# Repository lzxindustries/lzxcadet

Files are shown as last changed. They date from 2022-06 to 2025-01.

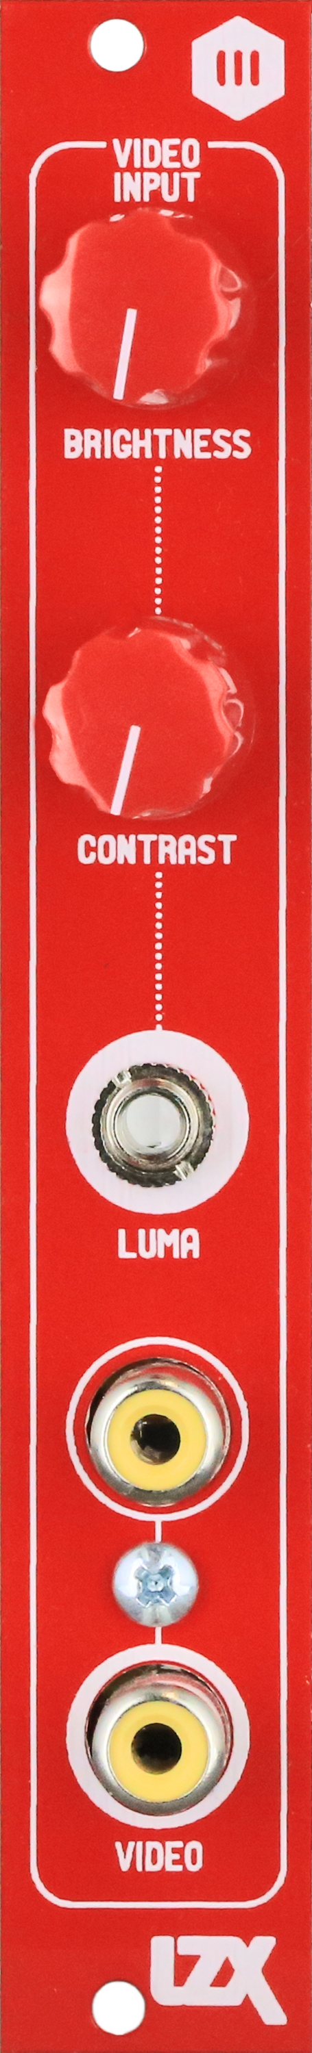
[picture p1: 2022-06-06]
C3/Images/LZX-Industries-Cadet-III-Video-Input-Front-Photo.png

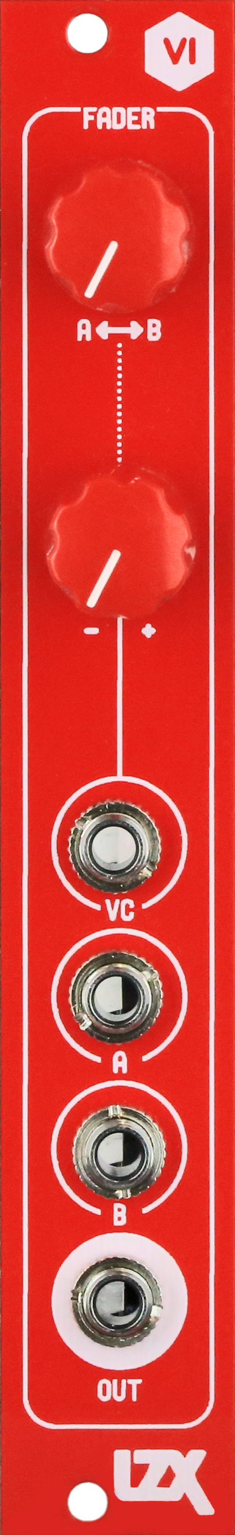
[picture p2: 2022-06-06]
C6/Images/LZX-Industries-Cadet-VI-Fader-Front-Photo.png

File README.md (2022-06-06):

# lzxcadet
LZX Cadet Series EuroRack Video Synthesizer DIY Modules

The designs and release artifacts for these projects are now open source hardware.

* You may fabricate any of the original PCB & Frontpanel Gerbers for personal use without restriction.

* You may not sell these modules, bare PCBs or kits with the original LZX artwork or under the LZX brand name.

* If you sell these modules, open source your derivative work and link back to this repository.

* If anyone is interested in maintaining this repository or revising the designs as a community project, please contact us.

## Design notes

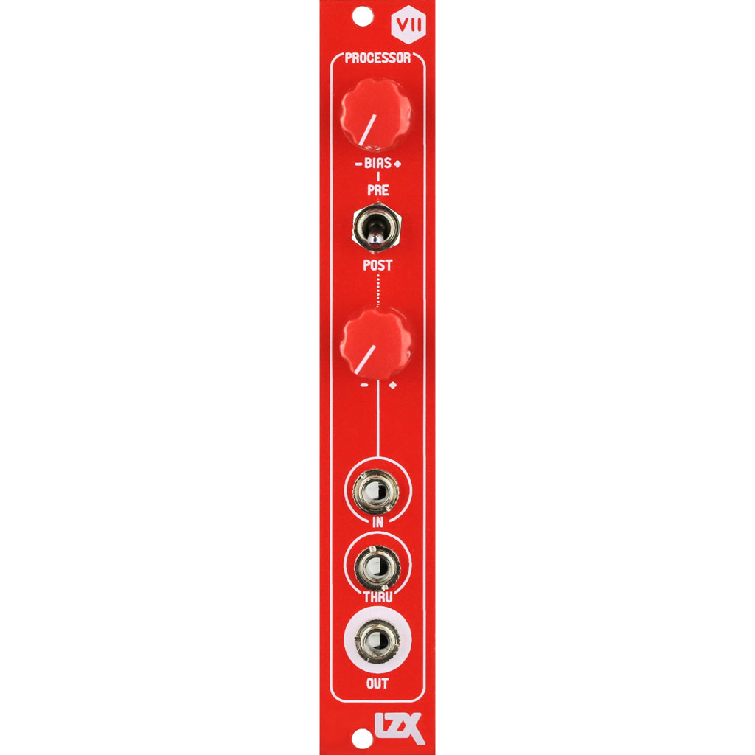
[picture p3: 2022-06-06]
C7/Images/LZX-Industries-Cadet-VII-Processor-Front-Photo_1024X1024.jpg

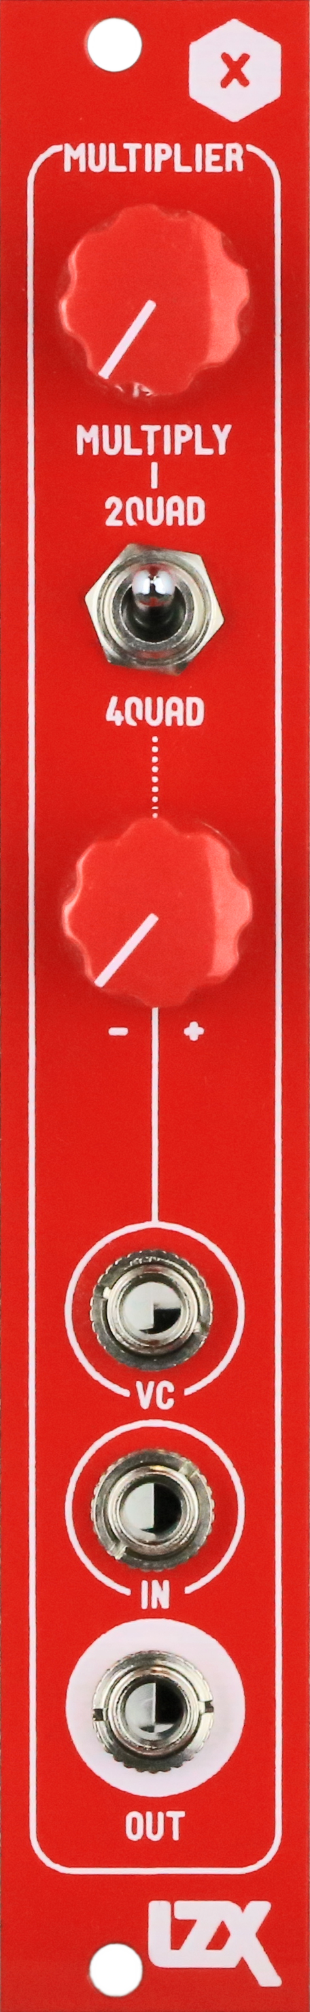
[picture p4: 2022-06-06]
C10/Images/LZX-Industries-Cadet-X-Multiplier-Front-Photo.png

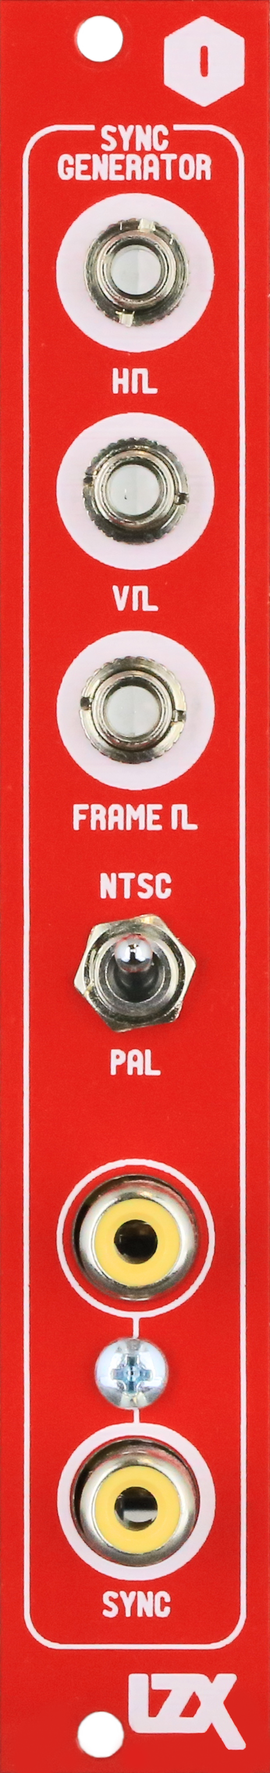
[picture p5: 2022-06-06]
C1/Images/LZX-Industries-Cadet-I-Sync-Generator-Front-Photo.png

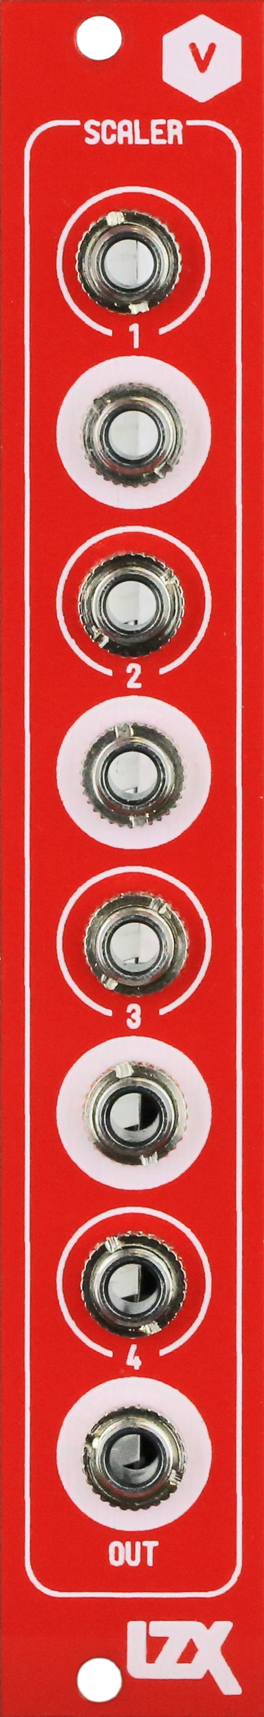
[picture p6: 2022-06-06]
C5/Images/LZX-Industries-Cadet-V-Scaler-Front-Photo.png

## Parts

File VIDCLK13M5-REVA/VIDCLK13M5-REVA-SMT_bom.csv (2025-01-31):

Quantity | Part No. | Notes | Product number | BOM number | Part description | Package
2 | 340009 | C1, C4 | 110312 | 110312 | SMT Capacitor 0805 16V X7R 10% 10uF | 0805
2 | 340004 | C5, C34 | 110312 | 110312 | SMT Capacitor 0603 50V X7R 10% 100nF | 0603
2 | 340002 | C56, C57 | 110312 | 110312 | SMT Capacitor 0603 50V X7R 10% 1uF | 0603
2 | 300008 | R1, R31 | 110312 | 110312 | SMT Resistor 0603 0.1W 1% 22R | 0603
1 | 300015 | R2 | 110312 | 110312 | SMT Resistor 0603 0.1W 1% 0R | 0603
1 | 329411 | U3 | 110312 | 110312 | SMT IC 74HC74PW TSSOP-14 | TSSOP-14
1 | 320001 | U16 | 110312 | 110312 | SMT IC Microchip MIC5504-3.3YM5 SOT23-5 | SOT23-5
1 | 330002 | X1 | 110312 | 110312 | SMT Crystal 357LB3I027M0000 VCXO 27MHz
1 | 100371 | PCB | 110312 | 110312

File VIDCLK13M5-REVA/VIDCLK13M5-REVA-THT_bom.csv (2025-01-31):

Quantity | Part No. | Notes | Product number | BOM number | Part description | Package
1 | 110312 | SMT Assembly | 120313 | 120313

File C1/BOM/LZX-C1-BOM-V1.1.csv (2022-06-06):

Line Item | Quantity | Reference Designators | Manufacturer | Manufacturer P/N | Vendor | Vendor P/N | Description | Value | Package | Part Type | Assembly Location | Cost Each | Cost Ext
1 | 1 | - | LZX Industries | LZX-C1-PCB | LZX Industries | LZX-C1-PCB | LZX Industries Cadet I Sync Generator PCB | - | - | Fabricated | - | 14.99 | 14.99
2 | 1 | - | LZX Industries | LZX-C1-FPN | LZX Industries | LZX-C1-FPN | LZX Industries Cadet I Sync Generator Frontpanel | - | - | Fabricated | - | 3.86 | 3.86
3 | 1 | C1 | Vishay / Sprague | 1C10Z5U334M050B | Mouser | 75-1C10Z5U334M050B | Multilayer Ceramic Capacitors MLCC - Leaded 0.33uF 50volts Z5U 20% 2.5mm L/S | 330 n | - | Through Hole | PCB Top | 0.26 | 0.26
4 | 13 | C3, C4, C5, C7, C8, C9, C10, C11, C13, C14, C15, C16, C22 | Vishay / Sprague | 1C10Z5U104M050B | Mouser | 75-1C10Z5U104M050B | Multilayer Ceramic Capacitors MLCC - Leaded 0.1uF 50volts Z5U 20% 2.5mm L/S | 0.1 u | - | Through Hole | PCB Top | 0.1 | 1.3
5 | 2 | C2, C6 | Panasonic | ECE-A1VKS100 | Mouser | 667-ECE-A1VKS100 | Aluminum Electrolytic Capacitors - Leaded 10UF 35V KS RADIAL | 10 u | - | Through Hole | PCB Top | 0.24 | 0.48
6 | 2 | C17, C19 | Vishay / BC Components | K102K15X7RH53L2 | Mouser | 594-K102K15X7RH53L2 | Multilayer Ceramic Capacitors MLCC - Leaded 1000pF 100volts 10% X7R 2.5mm LS | 1000 p | - | Through Hole | PCB Top | 0.1 | 0.2
7 | 1 | C18 | Xicon | 21RD747-RC | Mouser | 21RD747-RC | Multilayer Ceramic Capacitors MLCC - Leaded 47pF 50volts C0G 5% 2.5mm L/S | 47 p | - | Through Hole | PCB Top | 0.1 | 0.1
8 | 2 | D1, D2 | Fairchild Semiconductor | 1N4001 | Mouser | 512-1N4001 | Rectifiers Vr/50V Io/1A T/R | - | - | Through Hole | PCB Top | 0.16 | 0.32
9 | 2 | FB1, FB2 | Fair-Rite | 2743001111 | Mouser | 623-2743001111 | EMI Filter Beads, Chips & Arrays 43 BEAD ON LEAD Z=68 OHM @ 100MHz | - | - | Through Hole | PCB Top | 0.13 | 0.26
10 | 6 | R2, R5, R16, R17, R20, R23 | KOA Speer | MF1/4DCT52R4990F | Mouser | 660-MF1/4DCT52R4990F | Metal Film Resistors - Through Hole 1/4W 499 ohm 1% 500 OHM 1% | 499R | - | Through Hole | PCB Top | 0.12 | 0.72
11 | 1 | R10 | KOA Speer | MF1/4DCT52R4992F | Mouser | 660-MF1/4DCT52R4992F | Metal Film Resistors - Through Hole 1/4W 49.9K ohm 1% 500 OHM 1% | 49.9K | - | Through Hole | PCB Top | 0.12 | 0.12
12 | 3 | R1, R3, R15 | KOA Speer | MF1/4DCT52R3921F | Mouser | 660-MF1/4DCT52R3921F | Metal Film Resistors - Through Hole 1/4W 3.92K ohm 1% 4.99K OHM 1% | 3.92K | - | Through Hole | PCB Top | 0.12 | 0.36
13 | 1 | R9 | KOA Speer | MF1/4DCT52R6803F | Mouser | 660-MF1/4DCT52R6803F | Metal Film Resistors - Through Hole 680Kohms 1% 100PPM | 680K | - | Through Hole | PCB Top | 0.12 | 0.12
14 | 8 | R4, R6, R11, R12, R14, R18, R26, R28 | KOA Speer | MF1/4DCT52R1001F | Mouser | 660-MF1/4DCT52R1001F | Metal Film Resistors - Through Hole 1Kohms 1% 100PPM | 1K | - | Through Hole | PCB Top | 0.12 | 0.96
15 | 2 | R8, R19 | KOA Speer | MF1/4DCT52R75R0F | Mouser | 660-MF1/4DCT52R75R0F | Metal Film Resistors – Through Hole 1/4W 75 ohm 1% | 75R | - | Through Hole | PCB Top | 0.12 | 0.24
16 | 4 | R7, R21, R22, R24 | KOA Speer | MF1/4DCT52R1002F | Mouser | 660-MF1/4DCT52R1002F | Metal Film Resistors - Through Hole 10Kohms 1% 100PPM | 10K | - | Through Hole | PCB Top | 0.12 | 0.48
17 | 1 | R13 | TE Connectivity / Holsworthy | 1623934-1 | Mouser | 279-1623934-1 | Metal Film Resistors - Through Hole 0Ohm 1/4W LINK | 0R | - | Through Hole | PCB Top | 0.1 | 0.1
18 | 2 | U1, U2 | Texas Instruments | LM6172IN/NOPB | Mouser | 926-LM6172IN/NOPB | Operational Amplifiers - Op Amps Dual High Speed,Low Pwr Amp | - | DIP8 | Through Hole | PCB Top | 3.81 | 7.62
19 | 1 | U3 | STMicroelectronics | L7805CV | Mouser | 511-L7805CV | Linear Voltage Regulators 5.0V 1.0A Positive | - | TO220 | Through Hole | PCB Top | 0.43 | 0.43
20 | 1 | U5 | Atmel | ATMEGA88A-PU | Mouser | 556-ATMEGA88A-PU | 8-bit Microcontrollers - MCU AVR 8KB FLSH 512B EE 1KB SRAM-20MHz | - | DIP28 | Through Hole | PCB Top | 2.62 | 2.62
21 | 1 | U6 | Texas Instruments | LM1881N/NOPB | Mouser | 926-LM1881N/NOPB | Video ICs Video Sync Separator | - | DIP8 | Through Hole | PCB Top | 2.93 | 2.93
22 | 1 | U7 | Texas Instruments | SN74HC14N | Mouser | 595-SN74HC14N | Inverters Hex Schmitt-Trigger | - | DIP14 | Through Hole | PCB Top | 0.54 | 0.54
23 | 1 | U8 | Texas Instruments | CD74HC4538E | Mouser | 595-CD74HC4538E | Monostable Multivibrator Dual Retrig Mono | - | DIP16 | Through Hole | PCB Top | 0.73 | 0.73
24 | 1 | U9 | Texas Instruments | CD74HC4046AE | Mouser | 595-CD74HC4046AE | Phase Locked Loops - PLL PLL w/ VCO | - | DIP16 | Through Hole | PCB Top | 0.61 | 0.61
25 | 1 | X1 | Citizen Finedevice Co Ltd | CSX750VCB13.500M-UT | DigiKey | 300-8162-1-ND | OSC VCXO 13.5MHZ CMOS SMD | - | - | SMT | PCB Top | 3.32 | 3.32
26 | 3 | J2, J4, J6 | Wenzhou QingPu | PJ302M | Thonk | MECH_JK_PJ302M | Right angled 3.5mm Jack Sockets w/Knurled Nuts, No Washers | - | - | Through Hole | PCB Top / Frontpanel | 0.59 | 1.77
27 | 1 | J9 | - | - | Futurlec | IDCMH16 | 16 Pin Shrouded Male Headers IDC | - | - | Through Hole | PCB Top | 0.25 | 0.25
28 | 1 | J1 | - | - | Futurlec | IDCMH14 | 14 Pin Shrouded Male Headers IDC | - | - | Through Hole | PCB Top | 0.25 | 0.25
29 | 1 | J10 | - | - | Futurlec | HEADD6 | 6 Pin .100" St. Male Double Headers | - | - | Through Hole | PCB Top | 0.12 | 0.12
30 | 2 | J3, J5 | CUI | RCJ-044 | Mouser | 490-RCJ-044 | RCA Phono Connectors, Right Angle, Yellow | - | - | Through Hole | PCB Top | 1.77 | 3.54
31 | 1 | S1 | Mountain Switch | 10TF230 | Mouser | 10TF230 | Toggle Switches SPDT ON-ON RT ANGLE | - | - | Through Hole | PCB Top / Frontpanel | 3.86 | 3.86
32 | 1 | M1 | Keystone | 621 | Mouser | 534-621 | Mounting Hardware THRD BRKT STL Z PL | - | - | Mechanical | PCB Top / Frontpanel | 0.31 | 0.31
33 | 1 | - | - | - | Erthenvar | Ribbon Cable - 16 to 16 | 16 Pin IDC EuroRack Power Cable | - | - | Accessories | - | 1.75 | 1.75
34 | 2 | - | - | - | McMaster-Carr | 90272A106 | Zinc-Plated Steel Pan Head Phillips Machine Screw, 4-40 Thread, 1/4" Length | - | - | Mechanical | PCB Bottom / Frontpanel / M1 | 0.02 | 0.04
35 | 3 | - | - | - | Thonk | Knurled Nuts | Knurled Nuts for PJ302M Jacks | - | - | Mechanical | Frontpanel | 0.05 | 0.15
Totals | 76 |  |  |  |  |  |  |  |  |  |  |  | 55.71

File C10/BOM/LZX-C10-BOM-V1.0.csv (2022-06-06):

Line Item | Quantity | Reference Designators | Manufacturer | Manufacturer P/N | Vendor | Vendor P/N | Description | Value | Package | Part Type | Assembly Location | Cost Each | Cost Ext
1 | 1 | - | LZX Industries | LZX-C10-PCB | LZX Industries | LZX-C10-PCB | LZX Industries Cadet X Multiplier PCB | - | - | Fabricated | - | 10.08 | 10.08
2 | 1 | - | LZX Industries | LZX-C10-FPN | LZX Industries | LZX-C10-FPN | LZX Industries Cadet X Multiplier Frontpanel | - | - | Fabricated | - | 3.86 | 3.86
3 | 8 | C1, C3, C4, C5, C7, C8, C9, C10 | Vishay / Sprague | 1C10Z5U104M050B | Mouser | 75-1C10Z5U104M050B | Multilayer Ceramic Capacitors MLCC - Leaded 0.1uF 50volts Z5U 20% 2.5mm L/S | 0.1 u | - | Through Hole | PCB Top | 0.1 | 0.6
4 | 2 | C2, C6 | Panasonic | ECE-A1VKS100 | Mouser | 667-ECE-A1VKS100 | Aluminum Electrolytic Capacitors - Leaded 10UF 35V KS RADIAL | 10 u | - | Through Hole | PCB Top | 0.24 | 0.48
5 | 2 | D1, D2 | Fairchild Semiconductor | 1N4001 | Mouser | 512-1N4001 | Rectifiers Vr/50V Io/1A T/R | - | - | Through Hole | PCB Top | 0.16 | 0.32
6 | 2 | L1, L2 | Fair-Rite | 2743001111 | Mouser | 623-2743001111 | EMI Filter Beads, Chips & Arrays 43 BEAD ON LEAD Z=68 OHM @ 100MHz | - | - | Through Hole | PCB Top | 0.13 | 0.26
7 | 3 | R1, R12, R19 | KOA Speer | MF1/4DCT52R4990F | Mouser | 660-MF1/4DCT52R4990F | Metal Film Resistors - Through Hole 1/4W 499 ohm 1% 500 OHM 1% | 499R | - | Through Hole | PCB Top | 0.12 | 0.48
8 | 2 | R2, R18 | KOA Speer | MF1/4DCT52R4991F | Mouser | 660-MF1/4DCT52R4991F | Metal Film Resistors - Through Hole 1/4W 4.99K ohm 1% 4.99K OHM 1% | 4.99K | - | Through Hole | PCB Top | 0.12 | 0.24
9 | 2 | R3, R14 | KOA Speer | MF1/4DCT52R1003F2 | Mouser | 660-MF1/4DCT52R1003F | Metal Film Resistors - Through Hole 100Kohms 1% 100PPM | 100K | - | Through Hole | PCB Top | 0.12 | 0.36
10 | 3 | R5, R7, R13 | KOA Speer | MF1/4DCT52R1001F | Mouser | 660-MF1/4DCT52R1001F | Metal Film Resistors - Through Hole 1Kohms 1% 100PPM | 1K | - | Through Hole | PCB Top | 0.12 | 0.24
11 | 1 | R10 | KOA Speer | MF1/4DCT52R6650F | Mouser | 660-MF1/4DCT52R6650F | Metal Film Resistors � Through Hole 1/4W 665 ohm 1% | 665R | - | Through Hole | PCB Top | 0.12 | 0.24
12 | 5 | R8, R9, R11, R21, R22 | KOA Speer | MF1/4DCT52R1002F | Mouser | 660-MF1/4DCT52R1002F | Metal Film Resistors - Through Hole 10Kohms 1% 100PPM | 10K | - | Through Hole | PCB Top | 0.12 | 0.6
13 | 3 | R6, R16, R17 | KOA Speer | MF1/4DCT52R1501F | Mouser | 660-MF1/4DCT52R1501F | Metal Film Resistors - Through Hole 1/4W 1.5K ohm 1% 1.5K OHM 1% | 1.5K | - | Through Hole | PCB Top | 0.12 | 0.24
14 | 2 | R4, R20 | - | - | Thonk | Mech_Pot_Alpha | Right Angle B10K Alpha 9mm Potentiometer | B10K | - | Through Hole | PCB Top / Frontpanel | 1.95 | 3.9
16 | 1 | U1 | Texas Instruments | TL072IP | Mouser | 595-TL072IP | Operational Amplifiers - Op Amps Dual JFET In Low N | - | DIP8 | Through Hole | PCB Top | 0.65 | 0.65
17 | 1 | U2 | Linear Technology | LT1251CN#PBF | Linear Technology | LT1251CN#PBF | 40MHz Video Fader and DC Gain Controlled Amplifier | - | DIP16 | Through Hole | PCB Top | 7.33 | 7.33
18 | 2 | U3, U5 | Texas Instruments | LM6172IN/NOPB | Mouser | 926-LM6172IN/NOPB | Operational Amplifiers - Op Amps Dual High Speed,Low Pwr Amp | - | DIP8 | Through Hole | PCB Top | 3.86 | 3.86
19 | 1 | U4 | Texas Instruments | TL431BQLPR | Mouser | 595-TL431BQLPR | Voltage References Adjustable Precision Shunt Regulator | - | TO-92-3 | Through Hole | PCB Top | 0.65 | 0.65
20 | 3 | J1, J3, J4 | - | - | Thonk | MECH_JK_PJ302M | Right angled 3.5mm Jack Sockets w/Knurled Nuts, No Washers | - | - | Through Hole | PCB Top / Frontpanel | 0.59 | 2.36
21 | 1 | J5 | - | - | Futurlec | IDCMH16 | 16 Pin Shrouded Male Headers IDC | - | - | Through Hole | PCB Top | 0.25 | 0.25
22 | 1 | - | - | - | Erthenvar | Ribbon Cable - 16 to 16 | 16 Pin IDC EuroRack Power Cable | - | - | Accessories | - | 1.75 | 1.75
23 | 2 | - | - | - | Thonk | Davies_1900h | Davies 1900H Clone Red (6.35mm Round Shaft) | - | - | Control Knobs | R4, R20 shafts | 0.9 | 1.8
24 | 3 | - | - | - | Thonk | Knurled Nuts | Knurled Nuts for PJ302M Jacks | - | - | Mechanical | Frontpanel | 0.05 | 0.2
25 | 1 | S1 | Mountain Switch | 10TF230 | Mouser | 10TF230 | Toggle Switches SPDT ON-ON RT ANGLE | - | - | Through Hole | PCB Top / Frontpanel |  | 40.75

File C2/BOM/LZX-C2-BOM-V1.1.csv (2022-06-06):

Line Item | Quantity | Reference Designators | Manufacturer | Manufacturer P/N | Vendor | Vendor P/N | Description | Value | Package | Part Type | Assembly Location | Cost Each | Cost Ext
1 | 1 | - | LZX Industries | LZX-C2-PCB | LZX Industries | LZX-C2-PCB | LZX Industries Cadet II RGB Encoder PCB | - | - | Fabricated | - |  | 0
2 | 1 | - | LZX Industries | LZX-C2-FPN | LZX Industries | LZX-C2-FPN | LZX Industries Cadet II RGB Encoder Frontpanel | - | - | Fabricated | - |  | 0
3 | 1 | C1 | Vishay / Sprague | 1C10Z5U334M050B | Mouser | 75-1C10Z5U334M050B | Multilayer Ceramic Capacitors MLCC - Leaded 0.33uF 50volts Z5U 20% 2.5mm L/S | 330 n | - | Through Hole | PCB Top | 0.26 | 0.26
4 | 17 | C3, C4, C5, C7, C8, C10, C12, C13, C14, C15, C16, C22, C23, C24, C25, C26, C27 | Vishay / Sprague | 1C10Z5U104M050B | Mouser | 75-1C10Z5U104M050B | Multilayer Ceramic Capacitors MLCC - Leaded 0.1uF 50volts Z5U 20% 2.5mm L/S | 0.1 u | - | Through Hole | PCB Top | 0.1 | 1.7
5 | 2 | C2, C6 | Panasonic | ECE-A1VKS100 | Mouser | 667-ECE-A1VKS100 | Aluminum Electrolytic Capacitors - Leaded 10UF 35V KS RADIAL | 10 u | - | Through Hole | PCB Top | 0.24 | 0.48
6 | 2 | C9, C11 | TDK | FG18X7R1E105KRT06 | Mouser | 810-FG18X7R1E105KRT6 | Multilayer Ceramic Capacitors MLCC - Leaded 1uF 25volts X7R +/-10% LS=2.5mm | 1 u | - | Through Hole | PCB Top | 0.28 | 0.56
7 | 1 | C17 | DNP | DNP | DNP | DNP | DNP | 10 p | - | Through Hole | PCB Top | 0 | 0
8 | 2 | C18, C19 | Panasonic | ECA-0JM221 | Mouser | 667-ECA-0JM221 | Aluminum Electrolytic Capacitors - Leaded 220UF 6.3V ALUM LYTIC RADIAL | 220 u | - | Through Hole | PCB Top | 0.18 | 0.36
9 | 2 | C20, C21 | AVX | TAP106K025SCS | Mouser | 581-TAP106K025SCS | Tantalum Capacitors - Solid Leaded 25volts 10uF 10% | 10 u | - | Through Hole | PCB Top | 0.68 | 1.36
10 | 1 | C28 | DNP | DNP | DNP | DNP | DNP | 2.2 p – 22 p | - | Through Hole | PCB Top | 0 | 0
11 | 2 | D1, D2 | Fairchild Semiconductor | 1N4001 | Mouser | 512-1N4001 | Rectifiers Vr/50V Io/1A T/R | - | - | Through Hole | PCB Top | 0.16 | 0.32
12 | 2 | D3, D4 | Fairchild Semiconductor | 1N4148 | Mouser | 512-1N4148 | Diodes - General Purpose, Power, Switching 100V Io/200mA BULK | - | DO35 | Through Hole | PCB Top | 0.1 | 0.2
13 | 12 | D5, D6, D7, D8, D9, D10, D11, D12, D13, D14, D15, D16 | STMicroelectronics | 1N5711 | Mouser | 511-1N5711 | Schottky Diodes & Rectifiers 15mA 70 Volt | - | DO35 | Through Hole | PCB Top | 0.29 | 3.48
14 | 2 | FB1, FB2 | Fair-Rite | 2743001111 | Mouser | 623-2743001111 | EMI Filter Beads, Chips & Arrays 43 BEAD ON LEAD Z=68 OHM @ 100MHz | - | - | Through Hole | PCB Top | 0.13 | 0.26
15 | 3 | R1, R2, R6 | KOA Speer | MF1/4DCT52R4990F | Mouser | 660-MF1/4DCT52R4990F | Metal Film Resistors - Through Hole 1/4W 499 ohm 1% 500 OHM 1% | 499R | - | Through Hole | PCB Top | 0.12 | 0.36
16 | 1 | R38 | KOA Speer | MF1/4DCT52R4991F | Mouser | 660-MF1/4DCT52R4991F | Metal Film Resistors - Through Hole 1/4W 4.99K ohm 1% 500 OHM 1% | 4.99K | - | Through Hole | PCB Top | 0.12 | 0.12
17 | 3 | R13, R23, R32 | KOA Speer | MF1/4DCT52R1401F | Mouser | 660-MF1/4DCT52R1401F | Metal Film Resistors - Through Hole 1/4W 1.4K ohm 1% | 1.4K | - | Through Hole | PCB Top | 0.12 | 0.36
18 | 1 | R40 | KOA Speer | MF1/4DCT52R3481F | Mouser | 660-MF1/4DCT52R3481F | Metal Film Resistors - Through Hole 1/4W 3.48K ohm 1% | 3.48K | - | Through Hole | PCB Top | 0.12 | 0.12
19 | 3 | R3, R4, R14 | KOA Speer | MF1/4DCT52R1003F | Mouser | 660-MF1/4DCT52R1003F | Metal Film Resistors - Through Hole 100Kohms 1% 100PPM | 100K | - | Through Hole | PCB Top | 0.12 | 0.36
20 | 25 | R5, R10, R11, R12, R15, R16, R17, R18, R20, R21, R22, R24, R25, R26, R27, R28, R29, R30, R31, R33, R34, R35, R36, R37, R41 | KOA Speer | MF1/4DCT52R1001F | Mouser | 660-MF1/4DCT52R1001F | Metal Film Resistors - Through Hole 1Kohms 1% 100PPM | 1K | - | Through Hole | PCB Top | 0.12 | 3
21 | 2 | R7, R19 | KOA Speer | MF1/4DCT52R75R0F | Mouser | 660-MF1/4DCT52R75R0F | Metal Film Resistors – Through Hole 1/4W 75 ohm 1% | 75R | - | Through Hole | PCB Top | 0.12 | 0.24
22 | 2 | R8, R9 | KOA Speer | MF1/4DCT52R1002F | Mouser | 660-MF1/4DCT52R1002F | Metal Film Resistors - Through Hole 10Kohms 1% 100PPM | 10K | - | Through Hole | PCB Top | 0.12 | 0.24
23 | 5 | U1, U2, U6, U8, U9 | Texas Instruments | LM6172IN/NOPB | Mouser | 926-LM6172IN/NOPB | Operational Amplifiers - Op Amps Dual High Speed,Low Pwr Amp | - | DIP8 | Through Hole | PCB Top | 3.86 | 19.3
24 | 1 | U3 | STMicroelectronics | L7805CV | Mouser | 511-L7805CV | Linear Voltage Regulators 5.0V 1.0A Positive | - | TO220 | Through Hole | PCB Top | 0.43 | 0.43
25 | 1 | U7 | Texas Instruments | SN74HC14N | Mouser | 595-SN74HC14N | Inverters Hex Schmitt-Trigger | - | DIP14 | Through Hole | PCB Top | 0.54 | 0.54
26 | 1 | U4 | Analog Devices | AD724JRZ | Mouser | 584-AD724JRZ | Video ICs RGB-NTSC/PAL ENCODER | - | SOIC16 | SMT | PCB Top | 14.61 | 14.61
27 | 1 | U5 | Texas Instruments | CD4053BE | Mouser | 595-CD4053BE | Multiplexer Switch ICs Triple 2-Ch Analog | - | DIP16 | Through Hole | PCB Top | 0.51 | 0.51
28 | 1 | U11 | Texas Instruments | TL431BQLPR | Mouser | 595-TL431BQLPR | Voltage References Adjustable Precision Shunt Regulator | - | TO-92-3 | Through Hole | PCB Top | 0.65 | 0.65
29 | 1 | Y1 | ABRACON | ABL-3.579545MHZ-B2 | Mouser | 815-ABL-3.579545B2 | Crystals +/-20ppm 3.579545MHZ FUNDAMENTAL | - | HC49 | Through Hole | PCB Top | 0.39 | 0.39
30 | 1 | Y2 | ECS | ECS-44-20-4X | Mouser | 520-HCU443-20X | Crystals 4.433618MHz 20pF | - | HC49 | Through Hole | PCB Top | 0.53 | 0.53
31 | 3 | J2, J4, J6 | Wenzhou QingPu | PJ302M | Thonk | MECH_JK_PJ302M | Right angled 3.5mm Jack Sockets w/Knurled Nuts, No Washers | - | - | Through Hole | PCB Top / Frontpanel | 0.59 | 1.77
32 | 1 | J9 | - | - | Futurlec | IDCMH16 | 16 Pin Shrouded Male Headers IDC | - | - | Through Hole | PCB Top | 0.25 | 0.25
33 | 1 | J1 | - | - | Futurlec | IDCMH14 | 14 Pin Shrouded Male Headers IDC | - | - | Through Hole | PCB Top | 0.25 | 0.25
34 | 2 | J3, J5 | CUI | RCJ-044 | Mouser | 490-RCJ-044 | RCA Phono Connectors, Right Angle, Yellow | - | - | Through Hole | PCB Top | 1.77 | 3.54
35 | 1 | S1 | Mountain Switch | 10TF230 | Mouser | 10TF230 | Toggle Switches SPDT ON-ON RT ANGLE | - | - | Through Hole | PCB Top / Frontpanel | 3.86 | 3.86
36 | 1 | M1 | Keystone | 621 | Mouser | 534-621 | Mounting Hardware THRD BRKT STL Z PL | - | - | Mechanical | PCB Top / Frontpanel | 0.31 | 0.31
37 | 1 | - | - | - | Erthenvar | Ribbon Cable - 16 to 16 | 16 Pin IDC EuroRack Power Cable | - | - | Accessories | - | 1.75 | 1.75
38 | 1 | - | - | - | McMaster-Carr | 90272A106 | Zinc-Plated Steel Pan Head Phillips Machine Screw, 4-40 Thread, 1/4" Length | - | - | Mechanical | PCB Bottom / Frontpanel / M1 | 0.02 | 0.02
39 | 1 | J7 | DNP | DNP | DNP | DNP | DNP | - | - | - | - | 0 | 0
40 | 3 | - | - | - | Thonk | Knurled Nuts | Knurled Nuts for PJ302M Jacks | - | - | Mechanical | Frontpanel | 0.05 | 0.15
Totals | 115 |  |  |  |  |  |  |  |  |  |  |  | 62.64

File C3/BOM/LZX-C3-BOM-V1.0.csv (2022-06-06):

Line Item | Quantity | Reference Designators | Manufacturer | Manufacturer P/N | Vendor | Vendor P/N | Description | Value | Package | Part Type | Assembly Location | Cost Each | Cost Ext
1 | 1 | - | LZX Industries | LZX-C3-PCB | LZX Industries | LZX-C3-PCB | LZX Industries Cadet III Video Input PCB | - | - | Fabricated | - | 11.53 | 11.53
2 | 1 | - | LZX Industries | LZX-C3-FPN | LZX Industries | LZX-C3-FPN | LZX Industries Cadet III Video Input Frontpanel | - | - | Fabricated | - | 3.86 | 3.86
3 | 1 | C1 | Vishay / Sprague | 1C10Z5U334M050B | Mouser | 75-1C10Z5U334M050B | Multilayer Ceramic Capacitors MLCC - Leaded 0.33uF 50volts Z5U 20% 2.5mm L/S | 330 n | - | Through Hole | PCB Top | 0.26 | 0.26
4 | 2 | C2, C6 | Panasonic | ECE-A1VKS100 | Mouser | 667-ECE-A1VKS100 | Aluminum Electrolytic Capacitors - Leaded 10UF 35V KS RADIAL | 10 u | - | Through Hole | PCB Top | 0.1 | 0.2
5 | 14 | C3, C4, C5, C7, C8, C9, C10, C11, C12, C13, C14, C16, C20, C22 | Vishay / Sprague | 1C10Z5U104M050B | Mouser | 75-1C10Z5U104M050B | Multilayer Ceramic Capacitors MLCC - Leaded 0.1uF 50volts Z5U 20% 2.5mm L/S | 0.1 u | - | Through Hole | PCB Top | 0.24 | 3.36
6 | 2 | D1, D2 | Fairchild Semiconductor | 1N4001 | Mouser | 512-1N4001 | Rectifiers Vr/50V Io/1A T/R | - | - | Through Hole | PCB Top | 0.16 | 0.32
7 | 2 | D5, D6 | STMicroelectronics | 1N5711 | Mouser | 511-1N5711 | Schottky Diodes & Rectifiers 15mA 70 Volt | - | DO35 | Through Hole | PCB Top | 0.43 | 0.86
8 | 2 | FB1, FB2 | Fair-Rite | 2743001111 | Mouser | 623-2743001111 | EMI Filter Beads, Chips & Arrays 43 BEAD ON LEAD Z=68 OHM @ 100MHz | - | - | Through Hole | PCB Top | 0.13 | 0.26
9 | 1 | J2 | Wenzhou QingPu | PJ302M | Thonk | MECH_JK_PJ302M | Right angled 3.5mm Jack Sockets w/Knurled Nuts, No Washers | - | - | Through Hole | PCB Top / Frontpanel | 0.59 | 0.59
10 | 2 | J3, J4 | CUI | RCJ-044 | Mouser | 490-RCJ-044 | RCA Phono Connectors, Right Angle, Yellow | - | - | Through Hole | PCB Top | 1.77 | 3.54
11 | 1 | J9 | - | - | Futurlec | IDCMH16 | 16 Pin Shrouded Male Headers IDC | - | - | Through Hole | PCB Top | 0.25 | 0.25
12 | 1 | M1 | Keystone | 621 | Mouser | 534-621 | Mounting Hardware THRD BRKT STL Z PL | - | - | Mechanical | PCB Top / Frontpanel | 0.31 | 0.31
13 | 1 | Q1 | Fairchild Semiconductor | 2N3904BU | Mouser | 512-2N3904BU | Bipolar Transistors - BJT NPN Transistor General Purpose | - | TO-92-3 | Through Hole | PCB Top | 0.17 | 0.17
14 | 2 | R1, R3 | KOA Speer | MF1/4DCT52R1003F | Mouser | 660-MF1/4DCT52R1003F | Metal Film Resistors - Through Hole 100Kohms 1% 100PPM | 100K | - | Through Hole | PCB Top | 0.12 | 0.24
15 | 4 | R2, R13, R15, R24 | KOA Speer | MF1/4DCT52R1002F | Mouser | 660-MF1/4DCT52R1002F | Metal Film Resistors - Through Hole 10Kohms 1% 100PPM | 10K | - | Through Hole | PCB Top | 0.12 | 0.48
16 | 8 | R4, R5, R7, R10, R17, R18, R20, R21 | KOA Speer | MF1/4DCT52R1001F | Mouser | 660-MF1/4DCT52R1001F | Metal Film Resistors - Through Hole 1Kohms 1% 100PPM | 1K | - | Through Hole | PCB Top | 0.12 | 0.96
17 | 1 | R6 | KOA Speer | MF1/4DCT52R1401F | Mouser | 660-MF1/4DCT52R1401F | Metal Film Resistors - Through Hole 1.4Kohms 1% 100PPM | 1.4K | - | Through Hole | PCB Top | 0.12 | 0.12
18 | 2 | R8, R19 | KOA Speer | MF1/4DCT52R75R0F | Mouser | 660-MF1/4DCT52R75R0F | Metal Film Resistors – Through Hole 1/4W 75 ohm 1% | 75R | - | Through Hole | PCB Top | 0.12 | 0.24
19 | 1 | R9 | KOA Speer | MF1/4DCT52R6803F | Mouser | 660-MF1/4DCT52R6803F | Metal Film Resistors - Through Hole 680Kohms 1% 100PPM | 680K | - | Through Hole | PCB Top | 0.12 | 0.12
20 | 1 | R11 | KOA Speer | MF1/4DCT52R2491F | Mouser | 660-MF1/4DCT52R2491F | Metal Film Resistors - Through Hole 2.49Kohms 1% 100PPM | 2.49K | - | Through Hole | PCB Top | 0.12 | 0.12
21 | 2 | R12, R14 | - | - | Thonk | Mech_Pot_Alpha | Right Angle B10K Alpha 9mm Potentiometer | B10K | - | Through Hole | PCB Top / Frontpanel | 1.95 | 3.9
22 | 1 | R16 | KOA Speer | MF1/4DCT52R4990F | Mouser | 660-MF1/4DCT52R4990F | Metal Film Resistors - Through Hole 1/4W 499 ohm 1% | 499R | - | Through Hole | PCB Top | 0.12 | 0.12
23 | 1 | R22 | KOA Speer | MF1/4DCT52R4991F | Mouser | 660-MF1/4DCT52R4991F | Metal Film Resistors - Through Hole 1/4W 4.99K ohm 1% | 4.99K | - | Through Hole | PCB Top | 0.12 | 0.12
24 | 1 | R23 | KOA Speer | MF1/4DCT52R1502F | Mouser | 660-MF1/4DCT52R1502F | Metal Film Resistors - Through Hole 15Kohms 1% 100PPM | 15K | - | Through Hole | PCB Top | 0.12 | 0.12
25 | 1 | U3 | STMicroelectronics | L7805CV | Mouser | 511-L7805CV | Linear Voltage Regulators 5.0V 1.0A Positive | - | TO220 | Through Hole | PCB Top | 0.43 | 0.43
26 | 1 | U4 | Texas Instruments | CD4053BE | Mouser | 595-CD4053BE | Multiplexer Switch ICs Triple 2-Ch Analog | - | DIP16 | Through Hole | PCB Top | 0.51 | 0.51
27 | 2 | U5, U8 | Texas Instruments | LM6172IN/NOPB | Mouser | 926-LM6172IN/NOPB | Operational Amplifiers - Op Amps Dual High Speed,Low Pwr Amp | - | DIP8 | Through Hole | PCB Top | 3.86 | 7.72
28 | 1 | U6 | Texas Instruments | LM1881N/NOPB | Mouser | 926-LM1881N/NOPB | Video ICs Video Sync Separator | - | DIP8 | Through Hole | PCB Top | 2.93 | 2.93
29 | 1 | U9 | Texas Instruments | TL431BQLPR | Mouser | 595-TL431BQLPR | Voltage References Adjustable Precision Shunt Regulator | - | TO-92-3 | Through Hole | PCB Top | 0.65 | 0.65
30 | 1 | U10 | Texas Instruments | TL072IP | Mouser | 595-TL072IP | Operational Amplifiers - Op Amps Dual JFET In Low N | - | DIP8 | Through Hole | PCB Top | 0.65 | 0.65
31 | 1 | - | - | - | Erthenvar | Ribbon Cable - 16 to 16 | 16 Pin IDC EuroRack Power Cable | - | - | Accessories | - | 1.75 | 1.75
32 | 2 | - | - | - | McMaster-Carr | 90272A106 | Zinc-Plated Steel Pan Head Phillips Machine Screw, 4-40 Thread, 1/4" Length | - | - | Mechanical | PCB Bottom / Frontpanel / M1 | 0.02 | 0.04
33 | 2 | - | - | - | Thonk | Davies_1900h | Davies 1900H Clone Red (6.35mm Round Shaft) | - | - | Control Knobs | R12, R14 shafts | 0.9 | 1.8
34 | 1 | - | - | - | Thonk | Knurled Nuts | Knurled Nuts for PJ302M Jacks | - | - | Mechanical | Frontpanel | 0.05 | 0.05
Totals | 68 |  |  |  |  |  |  |  |  |  |  |  | 48.58

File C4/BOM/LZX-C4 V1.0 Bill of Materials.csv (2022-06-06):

Line Item | Quantity | Reference Designators | Manufacturer | Manufacturer P/N | Vendor | Vendor P/N | Description | Value | Package | Part Type | Assembly Location | Cost Each | Cost Ext
1 | 1 | - | LZX Industries | LZX-C4-PCB | LZX Industries | LZX-C4-PCB | LZX Industries Cadet IV Ramp Generator PCB | - | - | Fabricated | - | 18.74 | 18.74
2 | 1 | - | LZX Industries | LZX-C4-FPN | LZX Industries | LZX-C4-FPN | LZX Industries Cadet IV Ramp Generator Frontpanel | - | - | Fabricated | - | 3.86 | 3.86
3 | 1 | C1 | Vishay / Sprague | 1C10Z5U334M050B | Mouser | 75-1C10Z5U334M050B | Multilayer Ceramic Capacitors MLCC - Leaded 0.33uF 50volts Z5U 20% 2.5mm L/S | 330 n | - | Through Hole | PCB Top | 0.26 | 0.26
4 | 2 | C2, C6 | Panasonic | ECE-A1VKS100 | Mouser | 667-ECE-A1VKS100 | Aluminum Electrolytic Capacitors - Leaded 10UF 35V KS RADIAL | 10 u | - | Through Hole | PCB Top | 0.1 | 0.2
5 | 12 | C3, C4, C7, C8, C9, C10, C12, C15, C16, C17, C22, C25 | Vishay / Sprague | 1C10Z5U104M050B | Mouser | 75-1C10Z5U104M050B | Multilayer Ceramic Capacitors MLCC - Leaded 0.1uF 50volts Z5U 20% 2.5mm L/S | 0.1 u | - | Through Hole | PCB Top | 0.24 | 2.88
6 | 2 | D1, D2 | Fairchild Semiconductor | 1N4001 | Mouser | 512-1N4001 | Rectifiers Vr/50V Io/1A T/R | - | - | Through Hole | PCB Top | 0.16 | 0.32
7 | 4 | D3, D4, D5, D6 | STMicroelectronics | 1N5711 | Mouser | 511-1N5711 | Schottky Diodes & Rectifiers 15mA 70 Volt | - | DO35 | Through Hole | PCB Top | 0.43 | 1.72
8 | 2 | FB1, FB2 | Fair-Rite | 2743001111 | Mouser | 623-2743001111 | EMI Filter Beads, Chips & Arrays 43 BEAD ON LEAD Z=68 OHM @ 100MHz | - | - | Through Hole | PCB Top | 0.13 | 0.26
9 | 6 | J2, J3, J4, J6, J8, J10 | Wenzhou QingPu | PJ302M | Thonk | MECH_JK_PJ302M | Right angled 3.5mm Jack Sockets w/Knurled Nuts, No Washers | - | - | Through Hole | PCB Top / Frontpanel | 0.59 | 3.54
10 | 1 | J9 | - | - | Futurlec | IDCMH16 | 16 Pin Shrouded Male Headers IDC | - | - | Through Hole | PCB Top | 0.25 | 0.25
11 | 1 | J1 | - | - | Futurlec | IDCMH14 | 14 Pin Shrouded Male Headers IDC | - | - | Through Hole | PCB Top | 0.25 | 0.25
12 | 2 | R27, R45 | KOA Speer | MF1/4DCT52R1000F | Mouser | 660-MF1/4DCT52R1000F | Metal Film Resistors - Through Hole 100 ohms 1% 100PPM | 100R | - | Through Hole | PCB Top | 0.12 | 0.24
13 | 10 | R5, R6, R9, R10, R14, R16, R20, R24, R26, R43 | KOA Speer | MF1/4DCT52R1001F | Mouser | 660-MF1/4DCT52R1001F | Metal Film Resistors - Through Hole 1Kohms 1% 100PPM | 1K | - | Through Hole | PCB Top | 0.12 | 1.2
14 | 2 | R30, R48 | KOA Speer | MF1/4DCT52R2002F | Mouser | 660-MF1/4DCT52R2002F | Metal Film Resistors - Through Hole 20Kohms 1% 100PPM | 20K | - | Through Hole | PCB Top | 0.12 | 0.24
15 | 2 | R7, R11 | KOA Speer | MF1/4DCT52R2001F | Mouser | 660-MF1/4DCT52R2001F | Metal Film Resistors - Through Hole 2Kohms 1% 100PPM | 2K | - | Through Hole | PCB Top | 0.12 | 0.24
16 | 10 | R8, R12, R13, R15, R18, R31, R32, R33, R49, R50 | KOA Speer | MF1/4DCT52R4990F | Mouser | 660-MF1/4DCT52R4990F | Metal Film Resistors - Through Hole 1/4W 499 ohm 1% | 499R | - | Through Hole | PCB Top | 0.12 | 1.2
17 | 5 | R2, R4, R25, R38, R44 | KOA Speer | MF1/4DCT52R4991F | Mouser | 660-MF1/4DCT52R4991F | Metal Film Resistors - Through Hole 1/4W 4.99K ohm 1% | 4.99K | - | Through Hole | PCB Top | 0.12 | 0.6
18 | 1 | R40 | KOA Speer | MF1/4DCT52R1242F | Mouser | 660-MF1/4DCT52R1242F | Metal Film Resistors - Through Hole 10Kohms 1% 100PPM | 12.4K | - | Through Hole | PCB Top | 0.12 | 0.12
19 | 9 | R22, R23, R28, R29, R39, R41, R42, R46, R47 | KOA Speer | MF1/4DCT52R1002F | Mouser | 660-MF1/4DCT52R1002F | Metal Film Resistors - Through Hole 10Kohms 1% 100PPM | 10K | - | Through Hole | PCB Top | 0.12 | 1.08
20 | 1 | U3 | STMicroelectronics | L7805CV | Mouser | 511-L7805CV | Linear Voltage Regulators 5.0V 1.0A Positive | - | TO220 | Through Hole | PCB Top | 0.43 | 0.43
21 | 2 | U2, U5 | Texas Instruments | LM6172IN/NOPB | Mouser | 926-LM6172IN/NOPB | Operational Amplifiers - Op Amps Dual High Speed,Low Pwr Amp | - | DIP8 | Through Hole | PCB Top | 3.86 | 7.72
22 | 3 | U9, U10, U11 | Texas Instruments | TL431BQLPR | Mouser | 595-TL431BQLPR | Voltage References Adjustable Precision Shunt Regulator | - | TO-92-3 | Through Hole | PCB Top | 0.65 | 1.95
23 | 1 | U1 | Texas Instruments | TL072IP | Mouser | 595-TL072IP | Operational Amplifiers - Op Amps Dual JFET In Low N | - | DIP8 | Through Hole | PCB Top | 0.65 | 0.65
24 | 1 | - | - | - | Erthenvar | Ribbon Cable - 16 to 16 | 16 Pin IDC EuroRack Power Cable | - | - | Accessories | - | 1.75 | 1.75
25 | 2 | Q1, Q2 | Fairchild Semiconductor | 2N3906BU | Mouser | 512-2N3906BU | Bipolar Transistors - BJT PNP Transistor General Purpose | - | TO-92-3 | Through Hole | PCB Top | 0.19 | 0.38
26 | 1 | U7 | Texas Instruments | SN74HC14N | Mouser | 595-SN74HC14N | Inverters Hex Schmitt-Trigger | - | DIP14 | Through Hole | PCB Top | 0.54 | 0.54
27 | 2 | U12, U13 | Texas Instruments | TL074CN | Mouser | 595-TL074CN | Operational Amplifiers - Op Amps JFET Input Low Noise | - | DIP14 | Through Hole | PCB Top | 0.57 | 1.14
28 | 2 | Q3, Q4 | Fairchild Semiconductor | BS170 | Mouser | 512-BS170 | MOSFET N-Channel MOSFET | - | TO-92-3 | Through Hole | PCB Top | 0.39 | 0.78
29 | 2 | R1, R3 | Bourns | 3362P-1-103LF | Mouser | 652-3362P-1-103LF | Trimmer Resistors - Through Hole 1/4"SQ 10KOHMS 10% 0.5WATTS | 10K | - | Through Hole | PCB Top | 1.02 | 2.04
30 | 1 | C18 | TDK | FK11X5R1C156M | Mouser | 810-FK11X5R1C156M | Multilayer Ceramic Capacitors MLCC - Leaded 15uF 16volts X5R +/-20% | 15 u | - | Through Hole | PCB Top | 0.84 | 0.84
31 | 1 | C29 | AVX | SR205C563KAA | Mouser | 581-SR205C563KAA | Multilayer Ceramic Capacitors MLCC - Leaded 50volts 0.056uF 10% X7R | 56 n | - | Through Hole | PCB Top | 0.49 | 0.49
32 | 6 | - | - | - | Thonk | Knurled Nuts | Knurled Nuts for PJ302M Jacks | - | - | Mechanical | Frontpanel | 0.05 | 0.3
Totals | 99 |  |  |  |  |  |  |  |  |  |  |  | 56.21

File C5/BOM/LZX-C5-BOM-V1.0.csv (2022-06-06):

Line Item | Quantity | Reference Designators | Manufacturer | Manufacturer P/N | Vendor | Vendor P/N | Description | Value | Package | Part Type | Assembly Location | Cost Each | Cost Ext
1 | 1 | - | LZX Industries | LZX-C5-PCB | LZX Industries | LZX-C5-PCB | LZX Industries Cadet V Scaler PCB | - | - | Fabricated | - | 10.08 | 10.08
2 | 1 | - | LZX Industries | LZX-C5-FPN | LZX Industries | LZX-C5-FPN | LZX Industries Cadet V Scaler Frontpanel | - | - | Fabricated | - | 3.86 | 3.86
3 | 4 | C3, C4, C7, C8 | Vishay / Sprague | 1C10Z5U104M050B | Mouser | 75-1C10Z5U104M050B | Multilayer Ceramic Capacitors MLCC - Leaded 0.1uF 50volts Z5U 20% 2.5mm L/S | 0.1 u | - | Through Hole | PCB Top | 0.1 | 0.4
4 | 2 | C2, C6 | Panasonic | ECE-A1VKS100 | Mouser | 667-ECE-A1VKS100 | Aluminum Electrolytic Capacitors - Leaded 10UF 35V KS RADIAL | 10 u | - | Through Hole | PCB Top | 0.24 | 0.48
5 | 2 | D1, D2 | Fairchild Semiconductor | 1N4001 | Mouser | 512-1N4001 | Rectifiers Vr/50V Io/1A T/R | - | - | Through Hole | PCB Top | 0.16 | 0.32
6 | 2 | L1, L2 | Fair-Rite | 2743001111 | Mouser | 623-2743001111 | EMI Filter Beads, Chips & Arrays 43 BEAD ON LEAD Z=68 OHM @ 100MHz | - | - | Through Hole | PCB Top | 0.13 | 0.26
7 | 4 | R1, R3, R15, R17 | KOA Speer | MF1/4DCT52R2002F | Mouser | 660-MF1/4DCT52R2002F | Metal Film Resistors - Through Hole 1/4W 20K ohm 1% 20K OHM 1% | 20K | - | Through Hole | PCB Top | 0.12 | 0.48
8 | 4 | R2, R5, R16, R19 | KOA Speer | MF1/4DCT52R4990F | Mouser | 660-MF1/4DCT52R4990F | Metal Film Resistors - Through Hole 1/4W 499 ohm 1% 500 OHM 1% | 499R | - | Through Hole | PCB Top | 0.12 | 0.48
9 | 8 | R4, R6, R12, R14, R18, R20, R26, R28 | KOA Speer | MF1/4DCT52R4991F | Mouser | 660-MF1/4DCT52R4991F | Metal Film Resistors - Through Hole 1/4W 4.99K ohm 1% 4.99K OHM 1% | 4.99K | - | Through Hole | PCB Top | 0.12 | 0.96
10 | 11 | R7, R8, R9, R10, R11, R13, R25, R27, R29, R30, R31 | DNP | DNP | DNP | DNP | DO NOT PLACE | - | - | - | PCB Top | 0 | 0
11 | 2 | U1, U2 | Texas Instruments | TL072IP | Mouser | 595-TL072IP | Operational Amplifiers - Op Amps Dual JFET In Low N | - | DIP8 | Through Hole | PCB Top | 0.65 | 1.3
12 | 1 | U3 | DNP | DNP | DNP | DNP | DO NOT PLACE | - | - | - | PCB Top | 0 | 0
13 | 1 | U4 | DNP | DNP | DNP | DNP | DO NOT PLACE | - | - | - | PCB Top | 0 | 0
14 | 8 | J1, J2, J3, J4, J5, J6, J7, J8 | - | - | Thonk | MECH_JK_PJ302M | Right angled 3.5mm Jack Sockets w/Knurled Nuts, No Washers | - | - | Through Hole | PCB Top / Frontpanel | 0.59 | 4.72
15 | 1 | J9 | - | - | Futurlec | IDCMH16 | 16 Pin Shrouded Male Headers IDC | - | - | Through Hole | PCB Top | 0.25 | 0.25
16 | 1 | - | - | - | Erthenvar | Ribbon Cable - 16 to 16 | 16 Pin IDC EuroRack Power Cable | - | - | Accessories | - | 1.75 | 1.75
17 | 3 | C5, C9 | DNP | DNP | DNP | DNP | DO NOT PLACE | 0.1 u | - | Through Hole | PCB Top | 0 | 0
18 | 8 | - | - | - | Thonk | Knurled Nuts | Knurled Nuts for PJ302M Jacks | - | - | Mechanical | Frontpanel | 0.05 | 0.4
Totals | 64 |  |  |  |  |  |  |  |  |  |  |  | 25.74

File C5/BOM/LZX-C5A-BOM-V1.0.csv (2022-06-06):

Line Item | Quantity | Reference Designators | Manufacturer | Manufacturer P/N | Vendor | Vendor P/N | Description | Value | Package | Part Type | Assembly Location
1 | 1 | - | LZX Industries | LZX-C5-PCB | LZX Industries | LZX-C5-PCB | LZX Industries Cadet V Scaler PCB | - | - | Fabricated | -
2 | 1 | - | LZX Industries | LZX-C5-FPN | LZX Industries | LZX-C5-FPN | LZX Industries Cadet V Scaler Frontpanel | - | - | Fabricated | -
3 | 4 | C3, C4, C7, C8 | Vishay / Sprague | 1C10Z5U104M050B | Mouser | 75-1C10Z5U104M050B | Multilayer Ceramic Capacitors MLCC - Leaded 0.1uF 50volts Z5U 20% 2.5mm L/S | 0.1 u | - | Through Hole | PCB Top
4 | 2 | C2, C6 | Panasonic | ECE-A1VKS100 | Mouser | 667-ECE-A1VKS100 | Aluminum Electrolytic Capacitors - Leaded 10UF 35V KS RADIAL | 10 u | - | Through Hole | PCB Top
5 | 2 | D1, D2 | Fairchild Semiconductor | 1N4001 | Mouser | 512-1N4001 | Rectifiers Vr/50V Io/1A T/R | - | - | Through Hole | PCB Top
6 | 2 | L1, L2 | Fair-Rite | 2743001111 | Mouser | 623-2743001111 | EMI Filter Beads, Chips & Arrays 43 BEAD ON LEAD Z=68 OHM @ 100MHz | - | - | Through Hole | PCB Top
7 | 3 | R7, R10, R31 | TE Connectivity / Holsworthy | 1623934-1 | Mouser | 279-1623934-1 | Metal Film Resistors - Through Hole 0Ohm 1/4W LINK | 0R | - | Through Hole | PCB Top
7 | 4 | R1, R3, R15, R17 | KOA Speer | MF1/4DCT52R1001F | Mouser | 660-MF1/4DCT52R1001F | Metal Film Resistors - Through Hole 1/4W 1K ohm 1% 1K OHM 1% | 1K | - | Through Hole | PCB Top
8 | 4 | R2, R5, R16, R19 | KOA Speer | MF1/4DCT52R4990F | Mouser | 660-MF1/4DCT52R4990F | Metal Film Resistors - Through Hole 1/4W 499 ohm 1% 500 OHM 1% | 499R | - | Through Hole | PCB Top
9 | 4 | R11, R13, R25, R27 | KOA Speer | MF1/4DCT52R2491F | Mouser | 660-MF1/4DCT52R2491F | Metal Film Resistors - Through Hole 1/4W 2.49K ohm 1% 2.49K OHM 1% | 2.49K | - | Through Hole | PCB Top
9 | 4 | R12, R14, R26, R28 | KOA Speer | MF1/4DCT52R1002F | Mouser | 660-MF1/4DCT52R1002F | Metal Film Resistors - Through Hole 1/4W 10K ohm 1% 10K OHM 1% | 10K | - | Through Hole | PCB Top
10 | 4 | R8, R9, R29, R30 | DNP | DNP | DNP | DNP | DO NOT PLACE | - | - | - | PCB Top
11 | 3 | U1, U2, U4 | Texas Instruments | LM6172IN/NOPB | Mouser | 926-LM6172IN/NOPB | Operational Amplifiers - Op Amps Dual High Speed,Low Pwr Amp | - | DIP8 | Through Hole | PCB Top
12 | 1 | U3 | DNP | DNP | DNP | DNP | DO NOT PLACE | - | - | - | PCB Top
13 | 2 | C5, C9 | DNP | DNP | DNP | DNP | DO NOT PLACE | - | - | - | PCB Top
14 | 8 | J1, J2, J3, J4, J5, J6, J7, J8 | - | - | Thonk | MECH_JK_PJ302M | Right angled 3.5mm Jack Sockets w/Knurled Nuts, No Washers | - | - | Through Hole | PCB Top / Frontpanel
15 | 1 | J9 | - | - | Futurlec | IDCMH16 | 16 Pin Shrouded Male Headers IDC | - | - | Through Hole | PCB Top
16 | 1 | - | - | - | Erthenvar | Ribbon Cable - 16 to 16 | 16 Pin IDC EuroRack Power Cable | - | - | Accessories | -

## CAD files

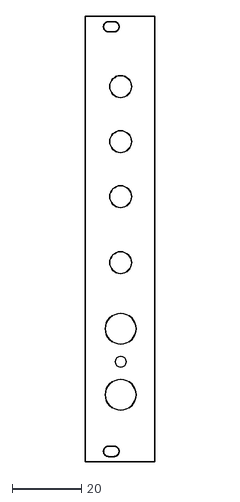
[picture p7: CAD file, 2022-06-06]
C1/Frontpanel/LZX-C1-FPN-V1.0.dxf
20.0 x 128.5

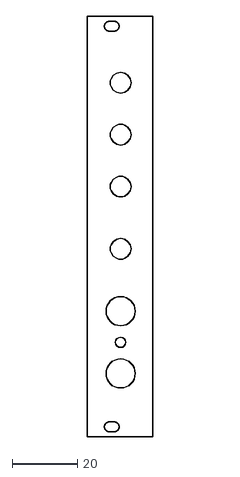
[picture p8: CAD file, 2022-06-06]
C2/Frontpanel/LZX-C2-FPN-V1.0.dxf
20.0 x 128.5

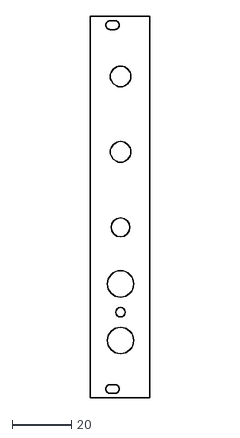
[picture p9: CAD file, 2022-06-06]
C3/Frontpanel/LZX-C3-FPN-V1.0.dxf
20.0 x 128.5

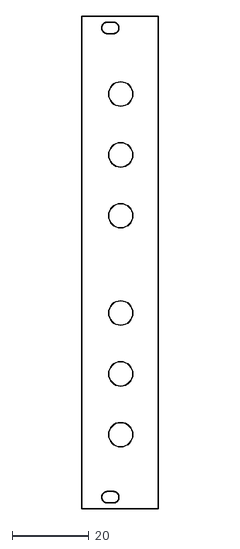
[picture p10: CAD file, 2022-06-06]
C4/Frontpanel/LZX-C4-FPN-V1.0.dxf
20.0 x 128.5

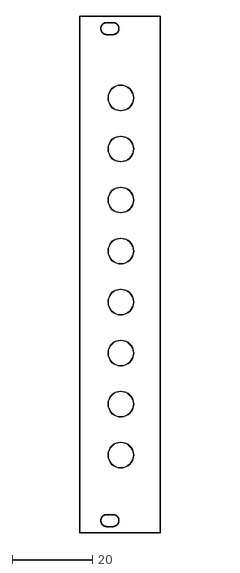
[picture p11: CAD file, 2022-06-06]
C5/Frontpanel/LZX-C5-FPN-V1.0.dxf
20.0 x 128.5

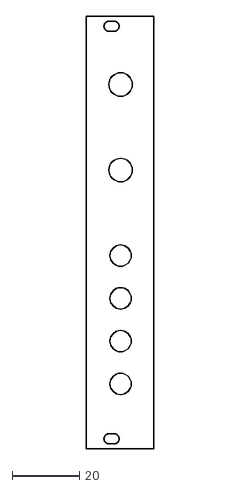
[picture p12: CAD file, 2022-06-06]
C6/Frontpanel/LZX-C6-FPN-V1.0.dxf
20.0 x 128.5

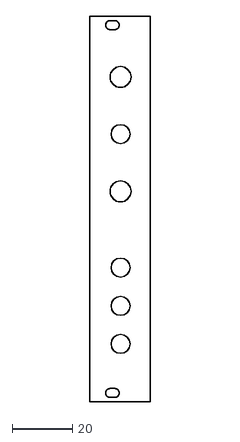
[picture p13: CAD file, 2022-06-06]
C7/Frontpanel/LZX-C7-FPN-V1.1.dxf
20.0 x 128.5

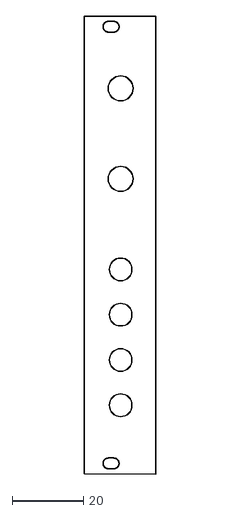
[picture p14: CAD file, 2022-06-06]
C8/Frontpanel/LZX-C8-FPN-V1.0.dxf
20.0 x 128.5

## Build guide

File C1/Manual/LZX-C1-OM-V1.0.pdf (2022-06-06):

# CADET I SYNC GENERATOR

# OWNER’S MANUAL

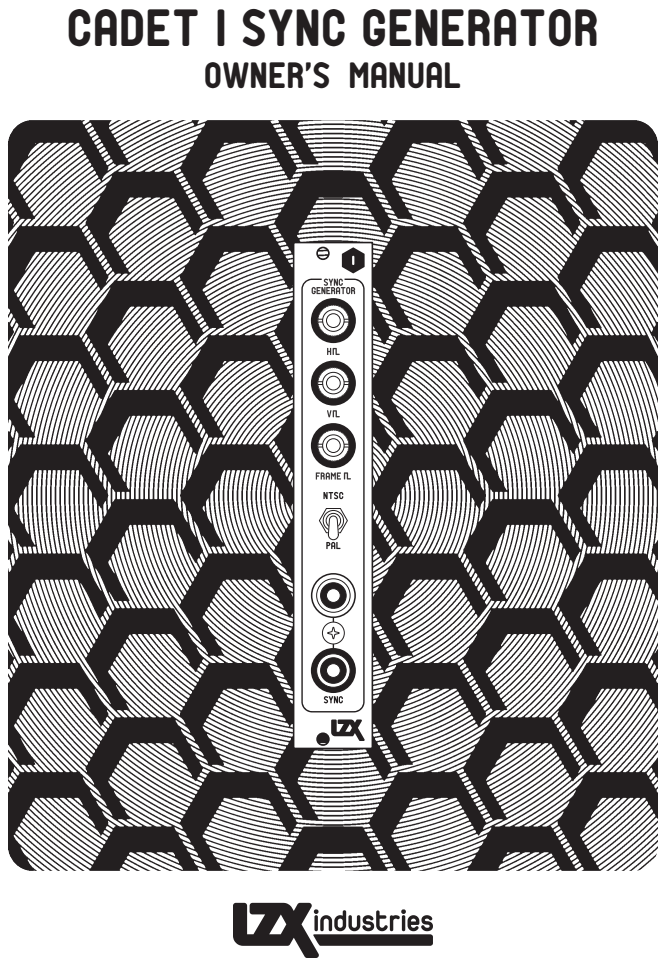
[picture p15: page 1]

# ABOUT THE CADET SERIES

i

LZX INDUSTRIES | CADET I SYNC GENERATOR

The practice of analog video synthesis has an inspiring legacy of innovators, sharers, and doers. In the early 70's, Dan Sandin released the hardware documentation of his Sandin Image Processor, a video instrument modeled after the Moog synthesizer. It contained several modules, an expandable architecture, and was an early example of what we now know as the open source movement.

In the mid 00's in Denton, Texas, I was diving deep into the tradition of synth DIY electronics when I stumbled across the documentation for the Sandin Image Processor and became enchanted. Teaming up with Ed Leckie in Sydney, Australia, we labored to adapt the circuits in ways that could be built with modern components. These efforts evolved into our own unique take on video synthesis, the LZX Industries format, and we began selling modules for the EuroRack synthesizer market in 2010.

With the Cadet series, we aim to take our work and give it back to the synth DIY and video hardware communities in a format we wished would have existed in the early days of our work. Each Cadet module performs a single function and is designed using through-hole parts where possible. Circuit schematics are published under the Creative Commons Attribution 4.0 International License. If our other product lines are recipes, Cadets are the ingredients. We encourage you to think outside the box, and to combine these circuits in new ways. Take the schematics, design your own modules and devices, and release them back into the world.

We salute you, Cadet! Go! Build!

Lars Larsen
September, 2016

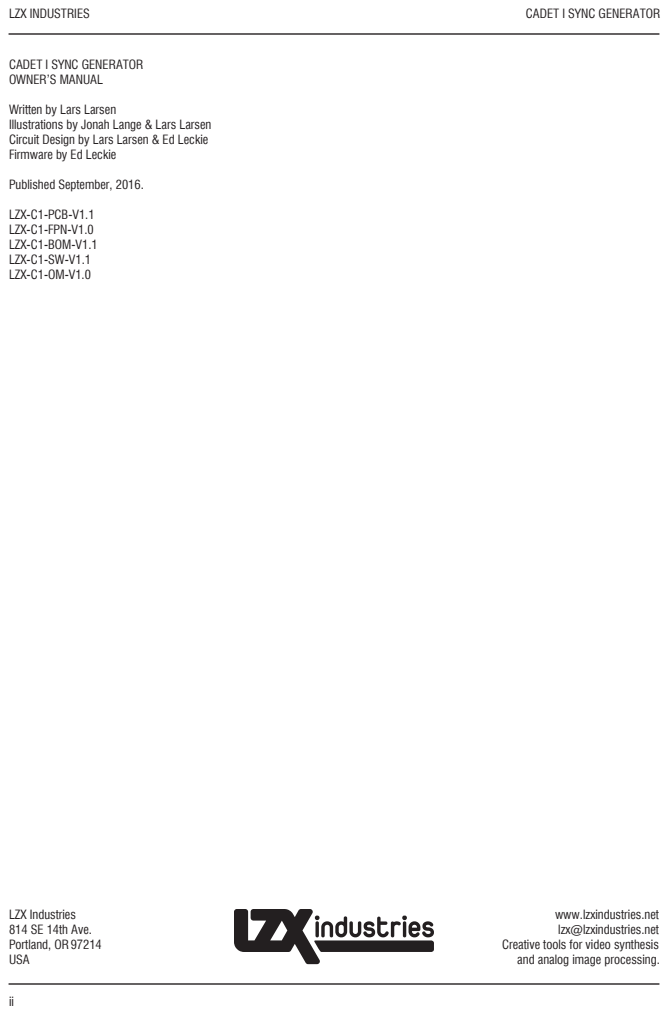
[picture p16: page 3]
LZX Industries 814 SE 14th Ave. Portland, OR 97214 USA

CADET I SYNC GENERATOR
OWNER’S MANUAL
Written by Lars Larsen
Illustrations by Jonah Lange & Lars Larsen
Circuit Design by Lars Larsen & Ed Leckie
Firmware by Ed Leckie
Published September, 2016.
LZX-C1-PCB-V1.1
LZX-C1-FPN-V1.0
LZX-C1-BOM-V1.1
LZX-C1-SW-V1.1
LZX-C1-OM-V1.0

www.lzxindustries.net
lzx@lzxindustries.net
and analog image processing.

Creative tools for video synthesis

FEATURES

# TABLE OF CONTENTS

iii

SPECIFICATIONS
USER CONTROLS & CONNECTIONS BLOCK DIAGRAM

1
1
2
2

DIY BUILD NOTES
COMPONENT PLacement DIAGRAM BILL OF MATERIALS

CIRCUIT DESIGN Notes

5
5
6

9
CREATIVE COMMONS LICENSE
MANUFACTURER WARRANTY

10
10
SCHEMATIC DIAGRAMS | 7
EXAMPLE PATCHES | 4
INSTALLATION | 3

Cadet I Sync Generator (C1) generates the master timing signals required for your modular video synthesizer in both NTSC and PAL formats. C1 includes a 14-pin video sync output header which transmits timing information to other modules, such as Cadet II RGB Encoder, or Cadet IV Ramp Generator. It can also synchronize its timing, and consequently that of your entire video synthesizer, to an external video source.

# FEATURES

Horizontal Sync Pulse, Vertical Sync Pulse, and Frame Clock outputs accessible from frontpanel.
NTSC/480i and PAL/576i timing modes.
Synchronization to an external video source through Video/Sync In. Buffered pass-through of external video signal. 14-pin video sync distribution header output on rear, to transmit video sync to other modules in the system.
Buffered distribution of Horizontal Sync Pulse and Vertical Sync Pulse outs to the EuroRack power header CV/Gate bus.

# SPECIFICATIONS

Format | EuroRack Synthesizer Module
EuroRack Width | 4HP
Mounting Depth | 2.25 inches (57.15 mm)
Frontpanel Dimensions | 0.788 inches (20.015 mm) * 5.059 inches (128.5 mm)
+12V Power Consumption | 30mA
-12V Power Consumption | 10mA
Series Output Resistance | 499 ohms (3.5mm outputs) 75 ohms (RCA outputs)
Input Termination Resistance | 100K ohms (3.5mm inputs) 75 ohms (RCA inputs)
Voltage Levels | 0-1V DC (3.5mm outputs) 0-5V DC (14-pin video sync distribution header outputs) 2Vpk-pk (RCA input/output)
Video Formats | NTSC/480i & PAL/576i
Video Sync Distribution Header Outputs | Composite Sync Vertical Sync Horizontal Sync Odd/Even Field Composite Blanking

4

5

6

1

2

3

Horizontal Sync Pulse Out. Positive-going pulse, 0-1V DC. Pulses at the beginning of each video scanline. 15,734Hz for NTSC. 15,625Hz for PAL. Useful for synchronizing oscillators running above these frequencies.

1

Vertical Sync Pulse Out. Positive-going pulse, 0-1V DC. Pulses at the beginning of each video field. 59.97Hz for NTSC, 50Hz for PAL. Useful for synchronizing oscillators running at frequencies above these frequencies, but below the horizontal sync pulse frequencies.

2

Frame Clock Out. Positive going pulse, 0-1V DC. Active high at the beginning of each video frame, and remains high during the odd numbered fields. Useful to drive sequencing at divisions of the video frame rate, or into clock dividers to create strobe sources.

3

Video Format Select Switch. Selects between NTSC (480i) and PAL (576i) sync timings. The desired setting must be selected prior to system power up.

4

5 Video/Sync In. Input an external video signal here to synchronize C1's timing to an external source.

Video/Sync Out. A buffered pass through of the Video/Sync Input. If you are synchronizing to an external camera, you could pass this signal to Cadet III Video Input (C3) to prepare that signal for patching throughout your system.

6

# USER CONTROLS & CONNECTIONS

# BLOCK DIAGRAM

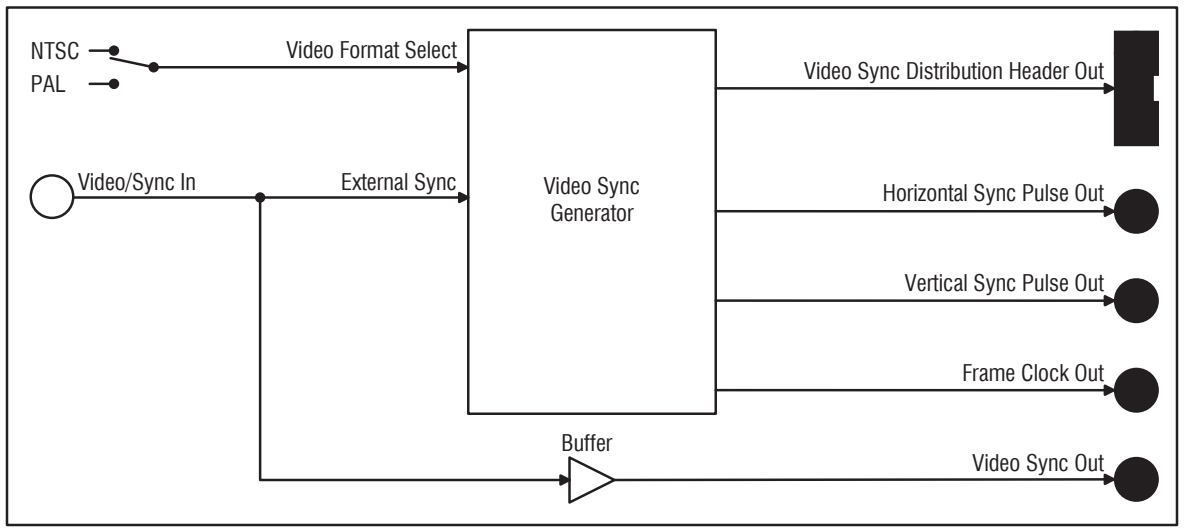
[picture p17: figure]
Video Sync Generator; Video/Sync In; Buffer; Video Sync Distribution Header Out; External Sync; Horizontal Sync Pulse Out; Vertical Sync Pulse Out; Frame Clock Out; Video Sync Out; NTSC PAL; Video Format Select

# INSTALLATION

Remove the module from its packaging and connect the 16-pin power cable to the keyed power entry header on the rear of the module as shown. Connect the other end of the power cable to an empty connector on your EuroRack power distribution busboard. Ensure pin 1 (-12V, with the red stripe) is oriented as indicated on your power distribution busboard.

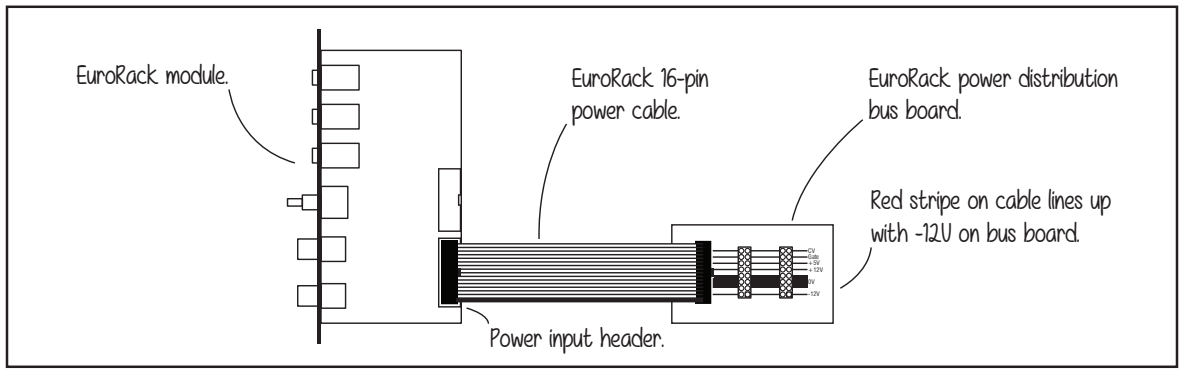
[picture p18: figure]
CV Gate +5V +12V; EuroRack module.; EuroRack 16-pin; power cable.; EuroRack power distribution bus board.; Power input header.; Red stripe on cable lines up with -12V on bus board.

This module requires connection to other video modules through the 14-pin sync distribution header. This is done through the use of the Video Sync Distribution Cable (VSDC) available from LZX Industries. VSDC is an expandable bus cable allowing attachment to up to 5 different modules. Connect one of the female connectors on the VSDC to the rear of the module as shown. Each module in your system with a 14-pin sync header in your system must be connected to each other in this manner. Multiple VSDCs may be chained together to provide an expandable bus if more than five connections are required.

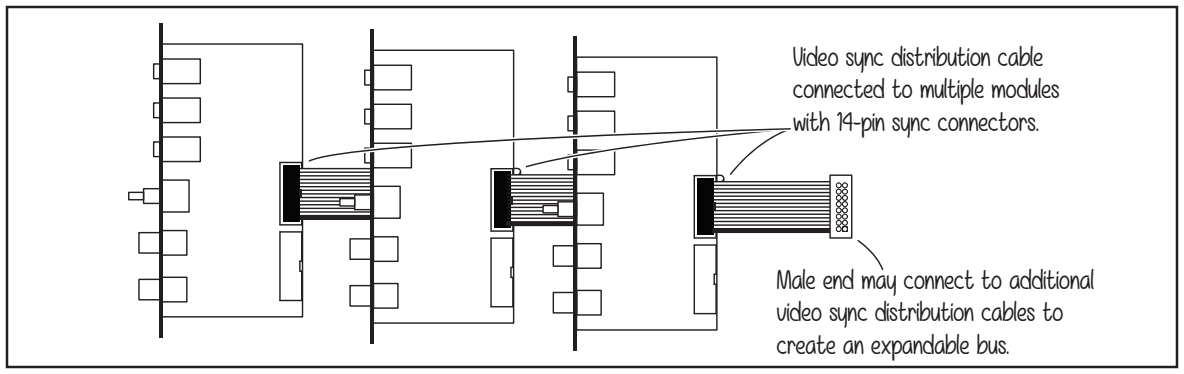
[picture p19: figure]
Video sync distribution cable connected to multiple modules with 14-pin sync connectors.; Male end may connect to additional video sync distribution cables to create an expandable bus.

After connecting power and sync cables, mount the module frontpanel flush to your enclosure's EuroRack mounting rails and secure the module with the mounting screws provided by your enclosure's manufacturer.

Power down your EuroRack case and disconnect it from AC power outlet while installing new modules.

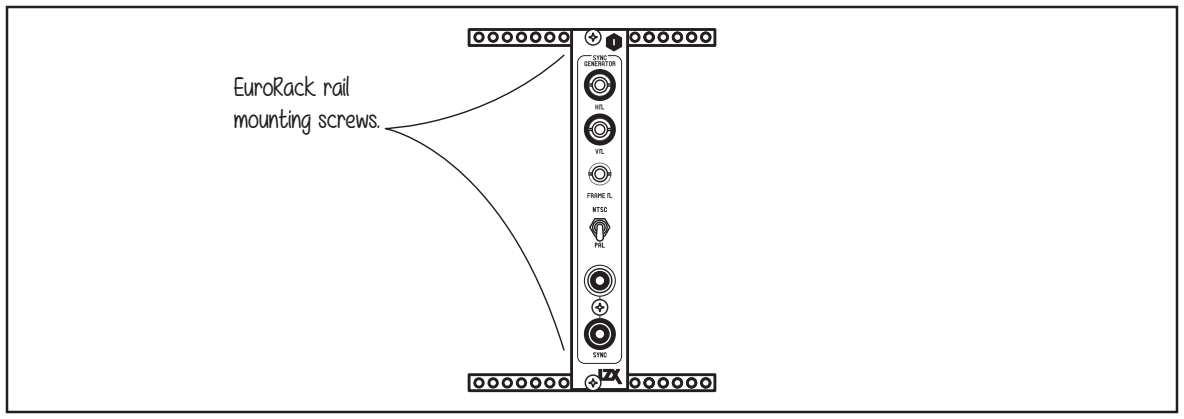
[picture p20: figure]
EuroRack rail mounting screws.

# EXAMPLE PATCHES

While a sync generator is an essential module for a video synthesizer, it does most of its magic by simply being there and performing its job behind the scenes. The most commo patch you will make with C1 is to synchronize your system’s timing to an external video source before patching that signal through to a video input amplifier, such as the Cadet III Video Input module.

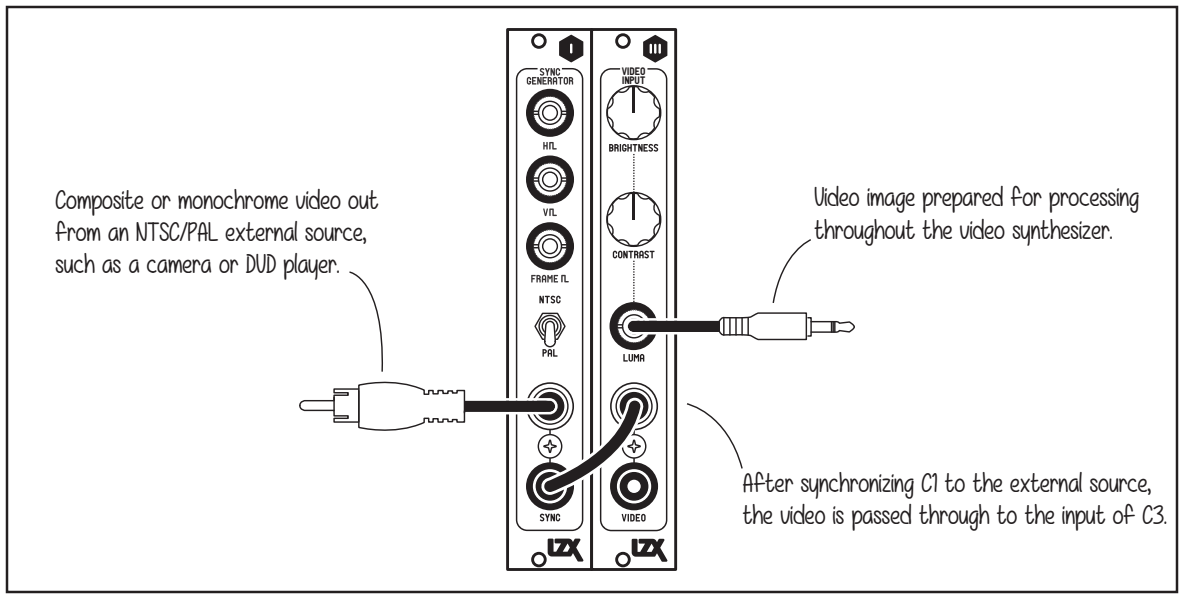
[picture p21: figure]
VIDEO INPUT; Composite or monochrome video out from an NTSC/PAL external source, such as a camera or DVD player.; Video image prepared for processing throughout the video synthesizer.

Most video pattern sources and oscillators designed by LZX will receive horizontal and vertical sync pulses through distribution behind the scenes, such as through the Video Sync Distribution output header or CV/Gate connectors on the power bus. However there may be cases in which you want to attempt synchronizing other sources, like EuroRack audio modules or laboratory test gear.

After synchronizing C1 to the external source, the video is passed through to the input of C3.

SYNCHRONIZING AND PROCESSING EXTERNAL VIDEO

SENDING VIDEO SYNC TO AUDIO OSCILLATORS

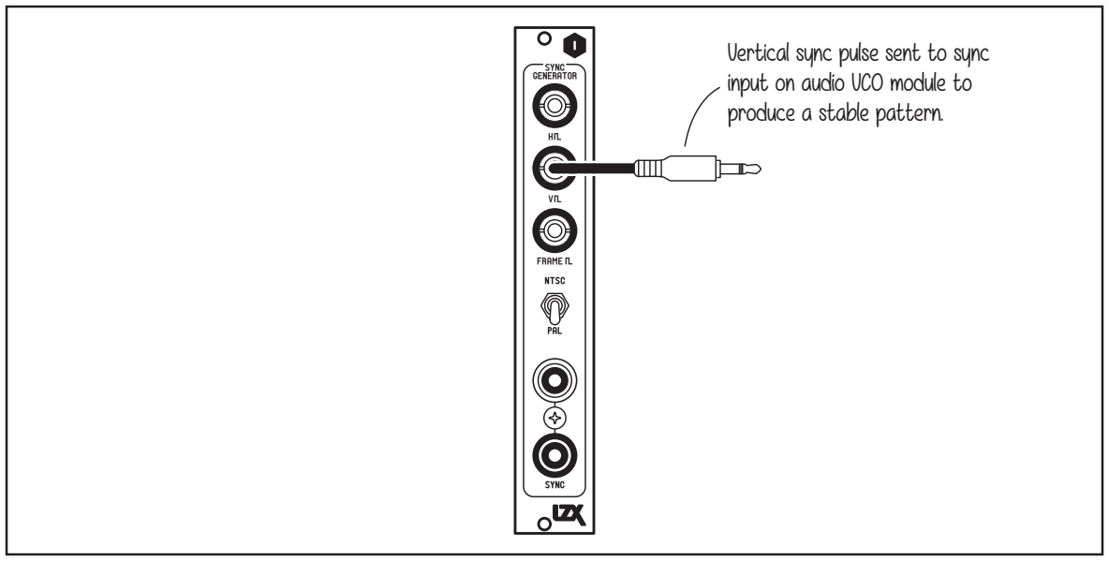
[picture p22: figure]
Vertical sync pulse sent to sync input on audio VCO module to produce a stable pattern.

# COMPONENT PLACEMENT DIAGRAM

# DIY BUILD NOTES

Cadet DIY kits are intended for intermediate level builders. If this is your first DIY electronics kit, or the amount of assembly information provided is inadequate, you may need to seek instructional material outside of the context of this owner’s manual.
We recommend mounting and installing components in the order they appear in the Bill of Materials.
If you can’t find the 10TF230 PCB mounted toggle switch or find it too expensive, any miniature toggle with a 1/4 inch bushing will work. Just use hookup wire or resistor clippings to the switch to the PCB pads. We recommend you mount the switch to the frontpanel before doing this.
If you don’t want to purchase an assembled Video Sync Distribution bus cable from LZX Industries, you can make your own configuration using 2X7 IDC Connectors and 14-pin ribbon cable.
We recommend securely attaching frontpanel mounted components to the frontpanel before soldering them to the PCB, if it can be managed. Keep the screws for the M1 mounting bracket slightly loose until the assembly is finalized.
The surface mount VC Crystal Oscillator (X1) should come assembled with your PCB from LZX Industries. At the time of this writing, this is a hard part to source and we have a limited quantity available. If you didn’t get your board with this part preassembled from us, the last source we used was DigiKey.
We are assuming you purchased a pre-programmed ATMEGA88A microprocessor from us, with the C1 firmware already installed. If you didn’t, you can easily install the firmware yourself via the 2X3 pin ISP header (J10) using an AVR programmer such as AVRISP-MKII and the Atmel Studio software available from Atmel. The firmware (ELF file) may be downloaded via our website.

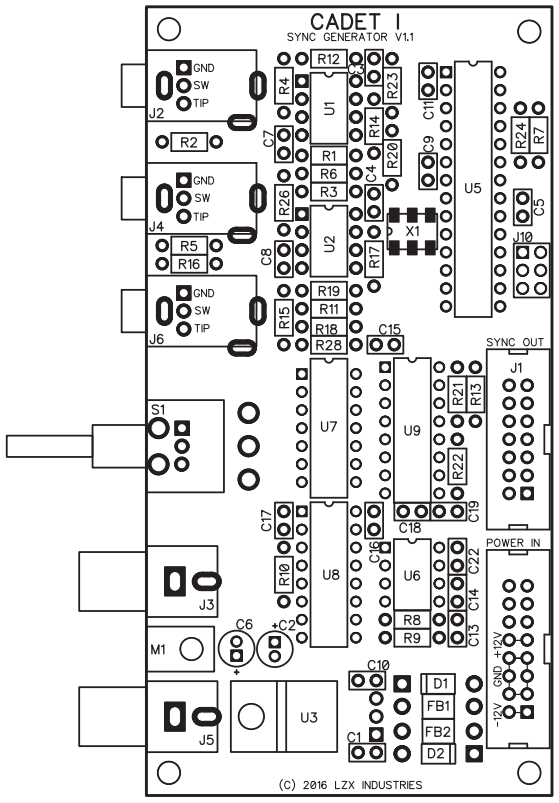
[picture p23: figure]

# BILL OF MATERIALS

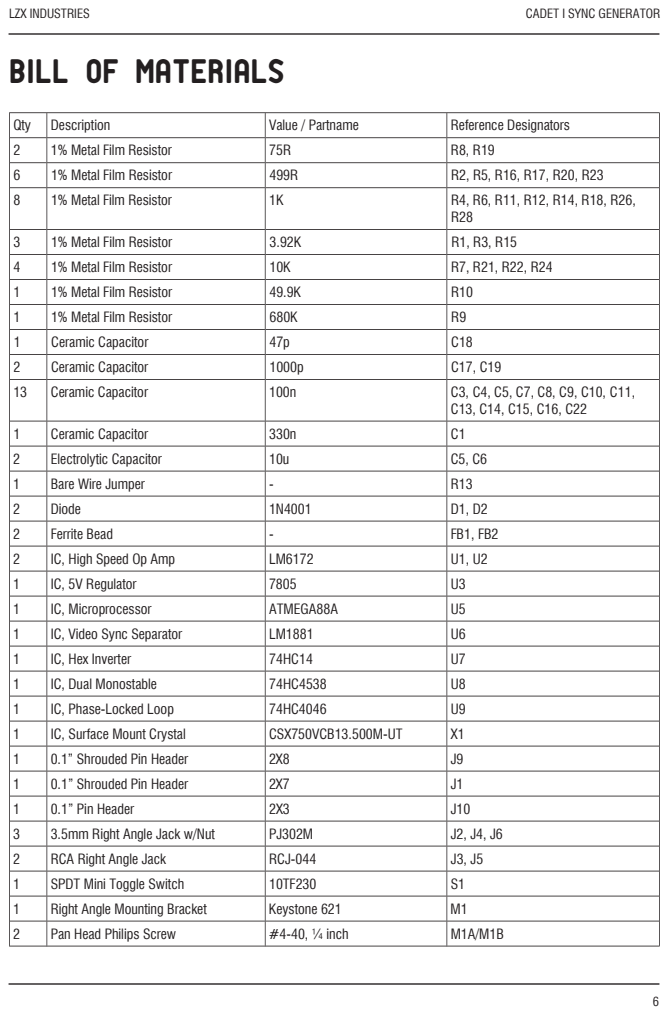
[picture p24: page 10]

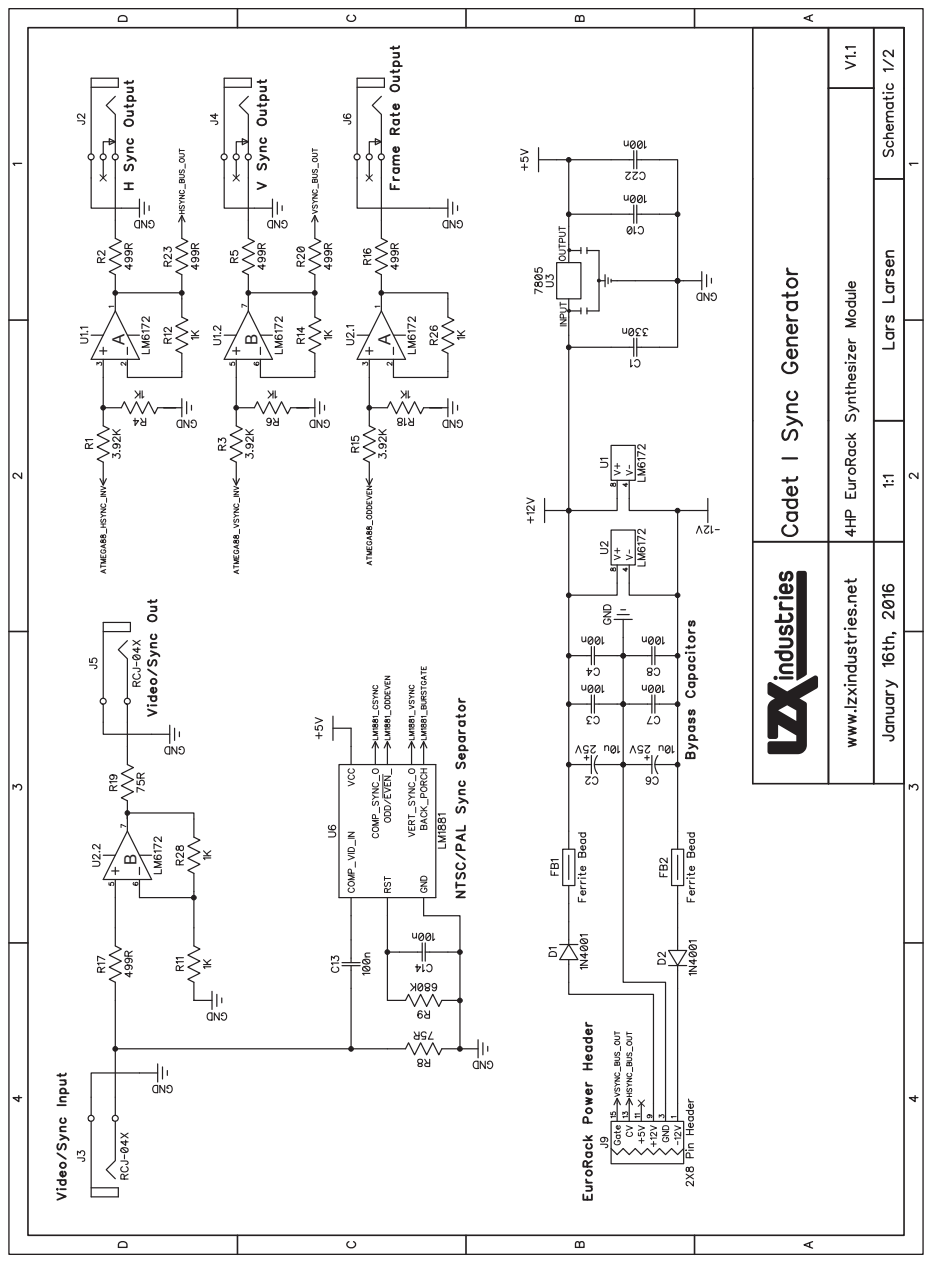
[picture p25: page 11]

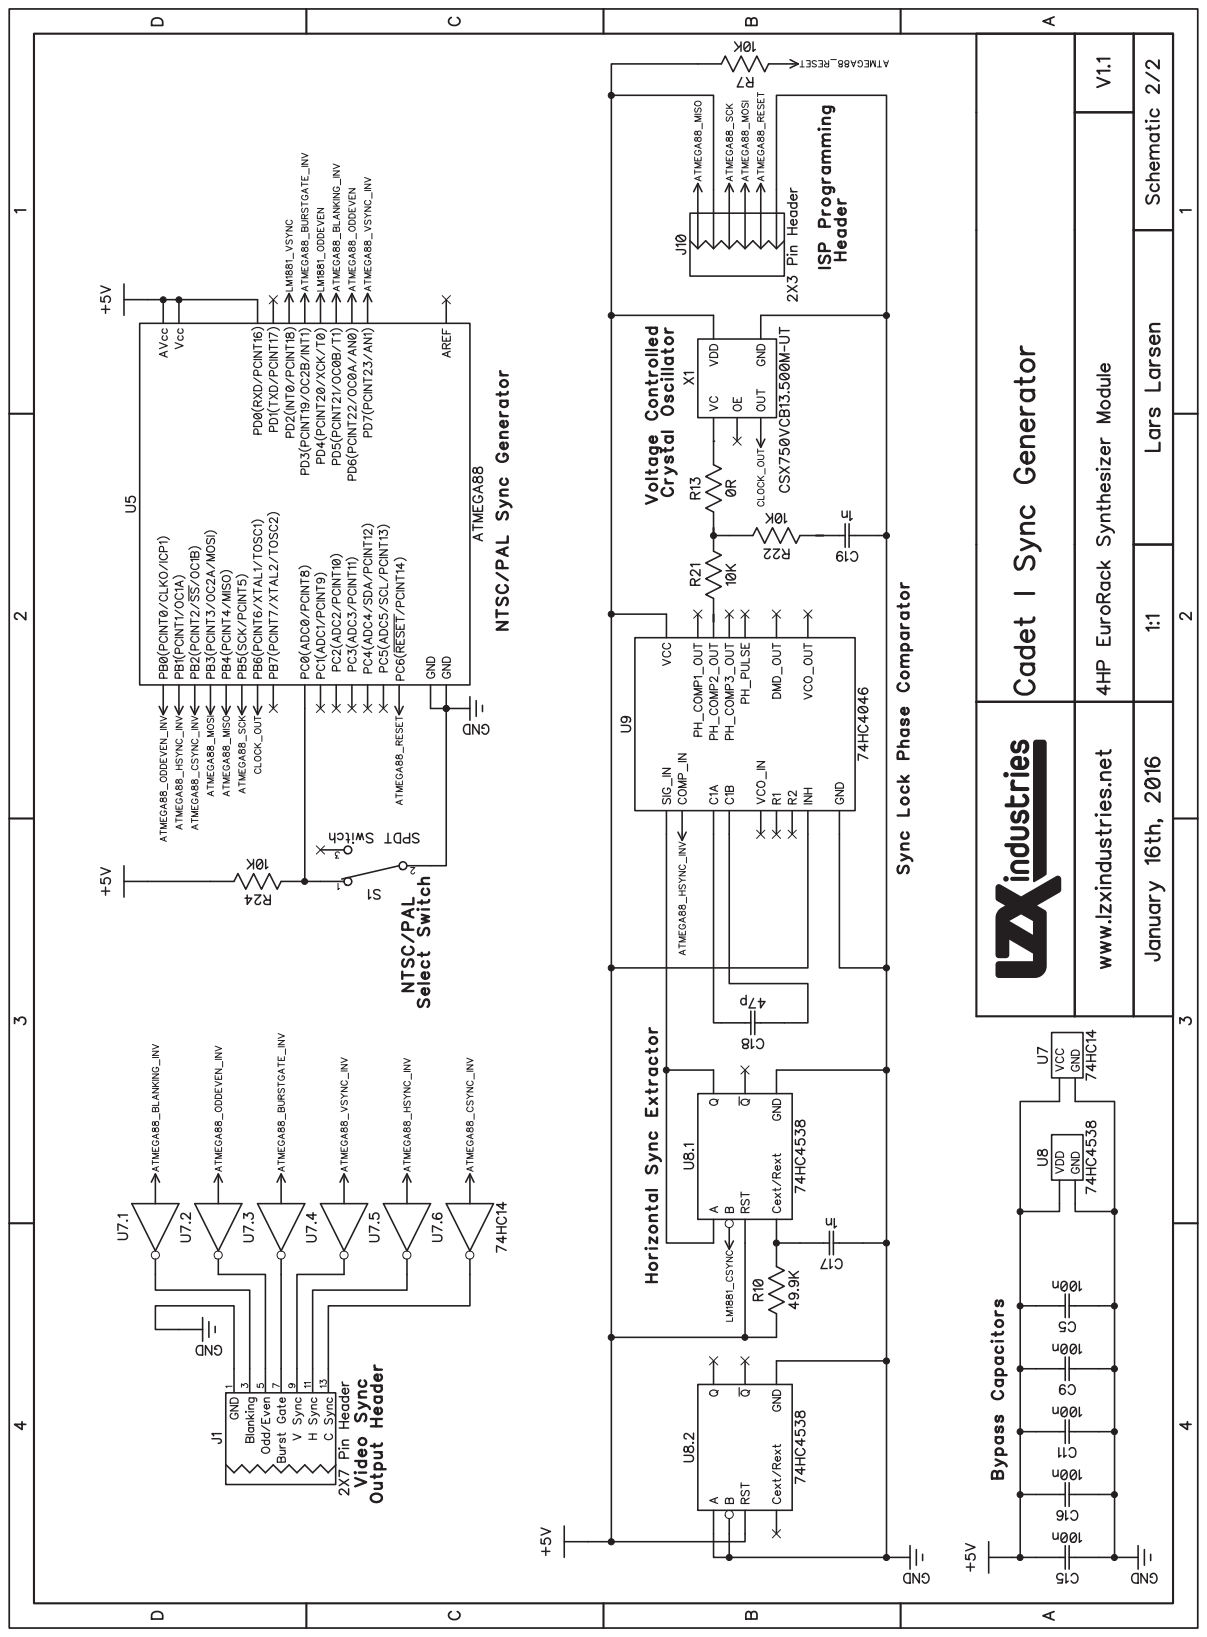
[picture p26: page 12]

# CIRCUIT DESIGN NOTes

The sync generator is the heartbeat of an analog video system. In the time the average human’s heart has beat once, the video system has displayed an image nearly thirty times. In each video image there are hundreds of scanlines. In each sweep of the cathode ray across the television display, there are hundreds of discernable shifts in color and brightness. Video is fast! So fast all you see is the streak left behind as it sprints. Analog video must keep moving, never missing a step, even when the images between your heartbeats appear motionless. Orchestrating this race of perfect visual rhythm is the function of your sync generator.

When we decided to build a video synthesizer, the sync generator was the first obstacle in our paths. There were no easy solutions, since most of the ICs in use as standalone video sync generators were long since out of production. We endeavored to find a solution which would not rely on any obsolete specialty ICs, and decided instead to use the ATMega88, a low-cost 8-bit microcontroller. We clocked the microcontroller with a 13.5MHz crystal resonator, a common clock speed for video systems, as it divides nicely down into intervals consistent with both NTSC and PAL timings. With my design partner’s skill in Assembly programming and experience with Atmel microcontrollers, we soon had a working video sync generator.

Cadet I Sync Generator is a direct adaptation of our early work, and you can find the ATMega88 as U5 in the schematic diagram. The U7 hex inverter buffers 5V sync outputs to a 14-pin distribution header for transmission to other modules in the video system. U1 and U2.1 buffer attenuated signals from the microcontroller to drive the Horizontal Sync Pulse, Vertical Sync Pulse, and Frame Clock output jacks on the frontpanel. Video sync is usually an active low signal, which is the inverse of what most synthesizer modules respond to, so the frontpanel outputs are inversions of broadcast standard HSync and VSync signals.

Understanding synchronization between two video systems requires another metaphor, that of two runners on a track, one of whom must match stride in perfect timing with the other. Your sync generator is running perfectly in time with itself, when a newcomer appears. The newcomer might be a video camera, or a DVD player, or even another video synthesizer. The two are running at roughly the same speed, but not yet in perfect sync with each other’s gait. Your sync generator observes the newcomer, perceptive and determined, making adjustments until its timing locks in perfect phase. Both devices now begin display of a video frame simultaneously, and each scanline also begins in tandem. This ability to synchronize with the timing of an external video device is known as genlock. It is what allows you to mix the output of your video synthesizer’s oscillators and patterns with external sources. Genlock is essential for a modular video system, as a studio of devices with genlock can all run the same race together.

This external synchronization feature was the next obstacle to conquer in our circuit. It was essential if we wanted to process external video sources in our fledgling video synthesizer. The LM1881 Video Sync Separator (U6) is a specialty IC designed to extract the synchronization pulses from any NTSC/PAL standard video signal. The external video signal at J3 connects to U6, giving us several video sync outputs which we send to our ATMega88 as inputs. This allows our sync generator to perform some tasks in time with the external source, such as reset the field with Vertical Sync and start a new frame in time with the Odd/Even gate. Matching the gait of the horizontal scanline requires more delicate control through locking the frequency of the 13.5MHz crystal oscillator (X1) with the phase of the external signal’s Horizontal Sync.

First, we need the external signal’s Horizontal Sync pulse, and LM1881 only offers us Composite Sync (a combination of horizontal and vertical syncs.) This is the function of the 74HC4538 monostable (multivibrator), U8, which takes the Composite Sync pulse and extracts only the horizontal information from it. Now that we have the Horizontal Sync pulse from the external signal, and the Horizontal Sync pulse we are generating internally, we can compare the phase of the two using the phase comparator function of the 74HC4046 phase-locked loop IC (U9.) Our goal is to control the frequency of the crystal so that the rising edges of both the external signal and the internal one occur simultaneously. When the external signal’s rising edge occurs after our internal signal’s rising edge, the output of U9 goes high, causing our crystal’s frequency to increase ever so slightly. When the opposite occurs, the output of U9 goes low, causing our crystal to slow down. When the phases match, the output floats -- causing no change in frequency. R21, R22 and C19 form a low pass filter so that these changes do not occur abruptly. Within milliseconds of observing the new runner, your sync generator’s shoes are hitting the track at the exact same nanosecond.

U2.2 is used to buffer the external video signal so it may be passed on to other destinations. You might send the external video signal to the input of C3 next, so it may be prepared for image processing through the rest of your system through DC restoration and scaling.

There is much more to learn about video formats, timing, and the function of the various video synchronization pulse outputs. We haven’t even touched on the color subcarrier -- something an LZX video synthesizer system typically generates only on output. I’ll leave that up to the many good texts on video engineering. But now you have something most of those texts don’t offer: a simple, practical example of how to generate NTSC/PAL sync and maintain genlock to an external source with commonly available ICs and at low cost.

We hope C1 will become the heartbeat of your own video device someday.

# CREATIVE COMMONS LICENSE

# MANUFACTURER’s WARRANTY

The circuit design and schematics for this work are licensed under a Creative Commons Attribution 4.0 International License. You may include this circuit with or without modification in commercial and non-commercial works. The PCB layout and frontpanel artwork are the property of LZX Industries and may not be cloned or replicated for commercial purposes. With the Cadet series, it is our intention to offer a resource to aid education and inspire the ongoing development and creation of tools for the video artist.

Read the full license and more at creativecommons.org.

Fully assembled versions of this product are covered by our manufacturer warranty for one year following the date of manufacture. This warranty covers any defect in the manufacturing of this product., such as assembly errors or faulty components. This warranty does not cover any damage or malfunction caused by incorrect use – such as, but not limited to, power cables connected backwards, excessive voltage levels, or exposure to extreme temperature or moisture levels. The warranty covers replacement or repair, as decided by the manufacturer. Please contact customer service via our website at www.lzxindustries.net for instructions on returning the product. The cost of returning a product for repair or replacement is paid for by the customer.

DIY kits and bare printed circuit boards are not covered under any warranty and come with no guarantee of assembly troubleshooting or customer support. However, we are nice and will help you when possible. Please contact us if you have questions about or problems with your build.

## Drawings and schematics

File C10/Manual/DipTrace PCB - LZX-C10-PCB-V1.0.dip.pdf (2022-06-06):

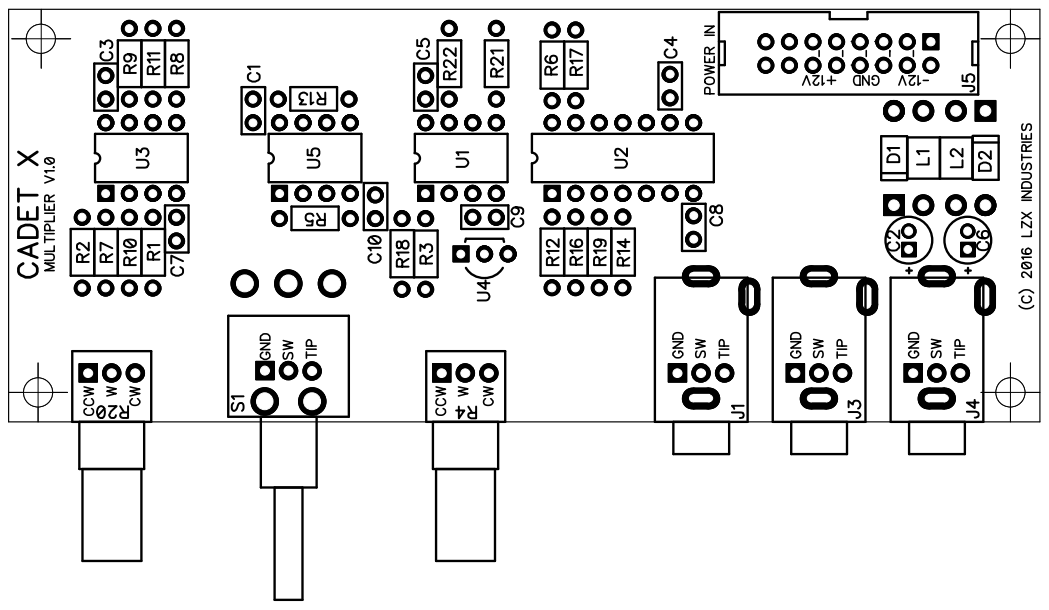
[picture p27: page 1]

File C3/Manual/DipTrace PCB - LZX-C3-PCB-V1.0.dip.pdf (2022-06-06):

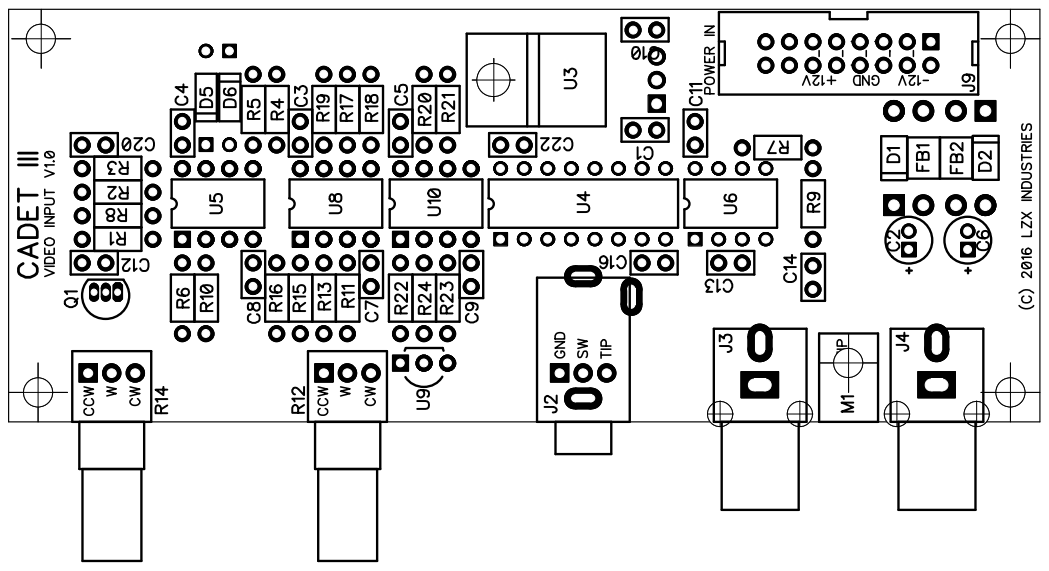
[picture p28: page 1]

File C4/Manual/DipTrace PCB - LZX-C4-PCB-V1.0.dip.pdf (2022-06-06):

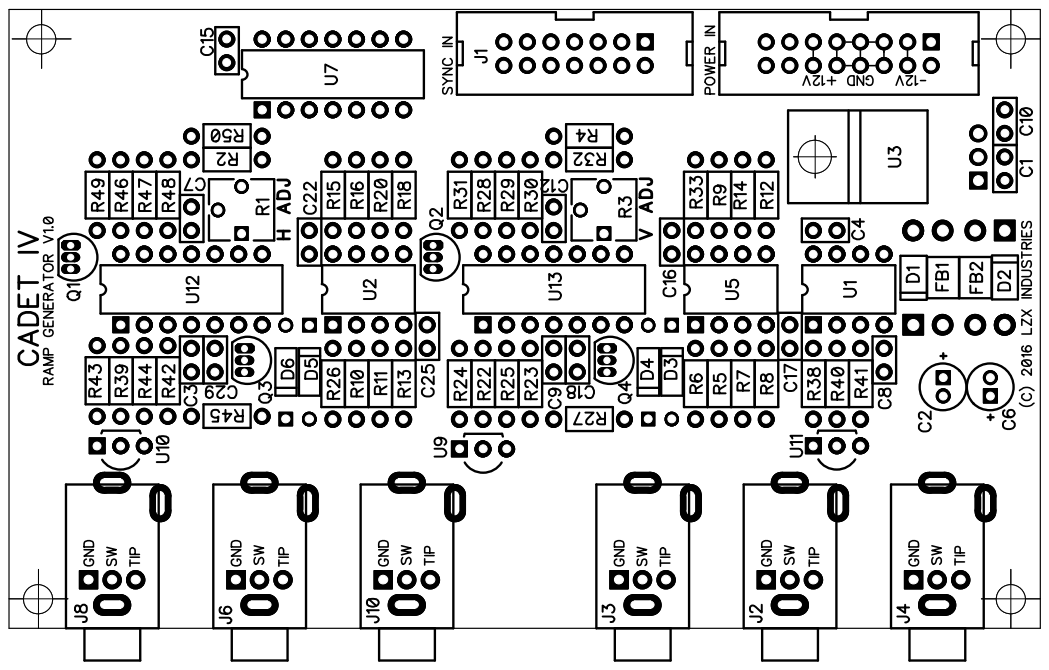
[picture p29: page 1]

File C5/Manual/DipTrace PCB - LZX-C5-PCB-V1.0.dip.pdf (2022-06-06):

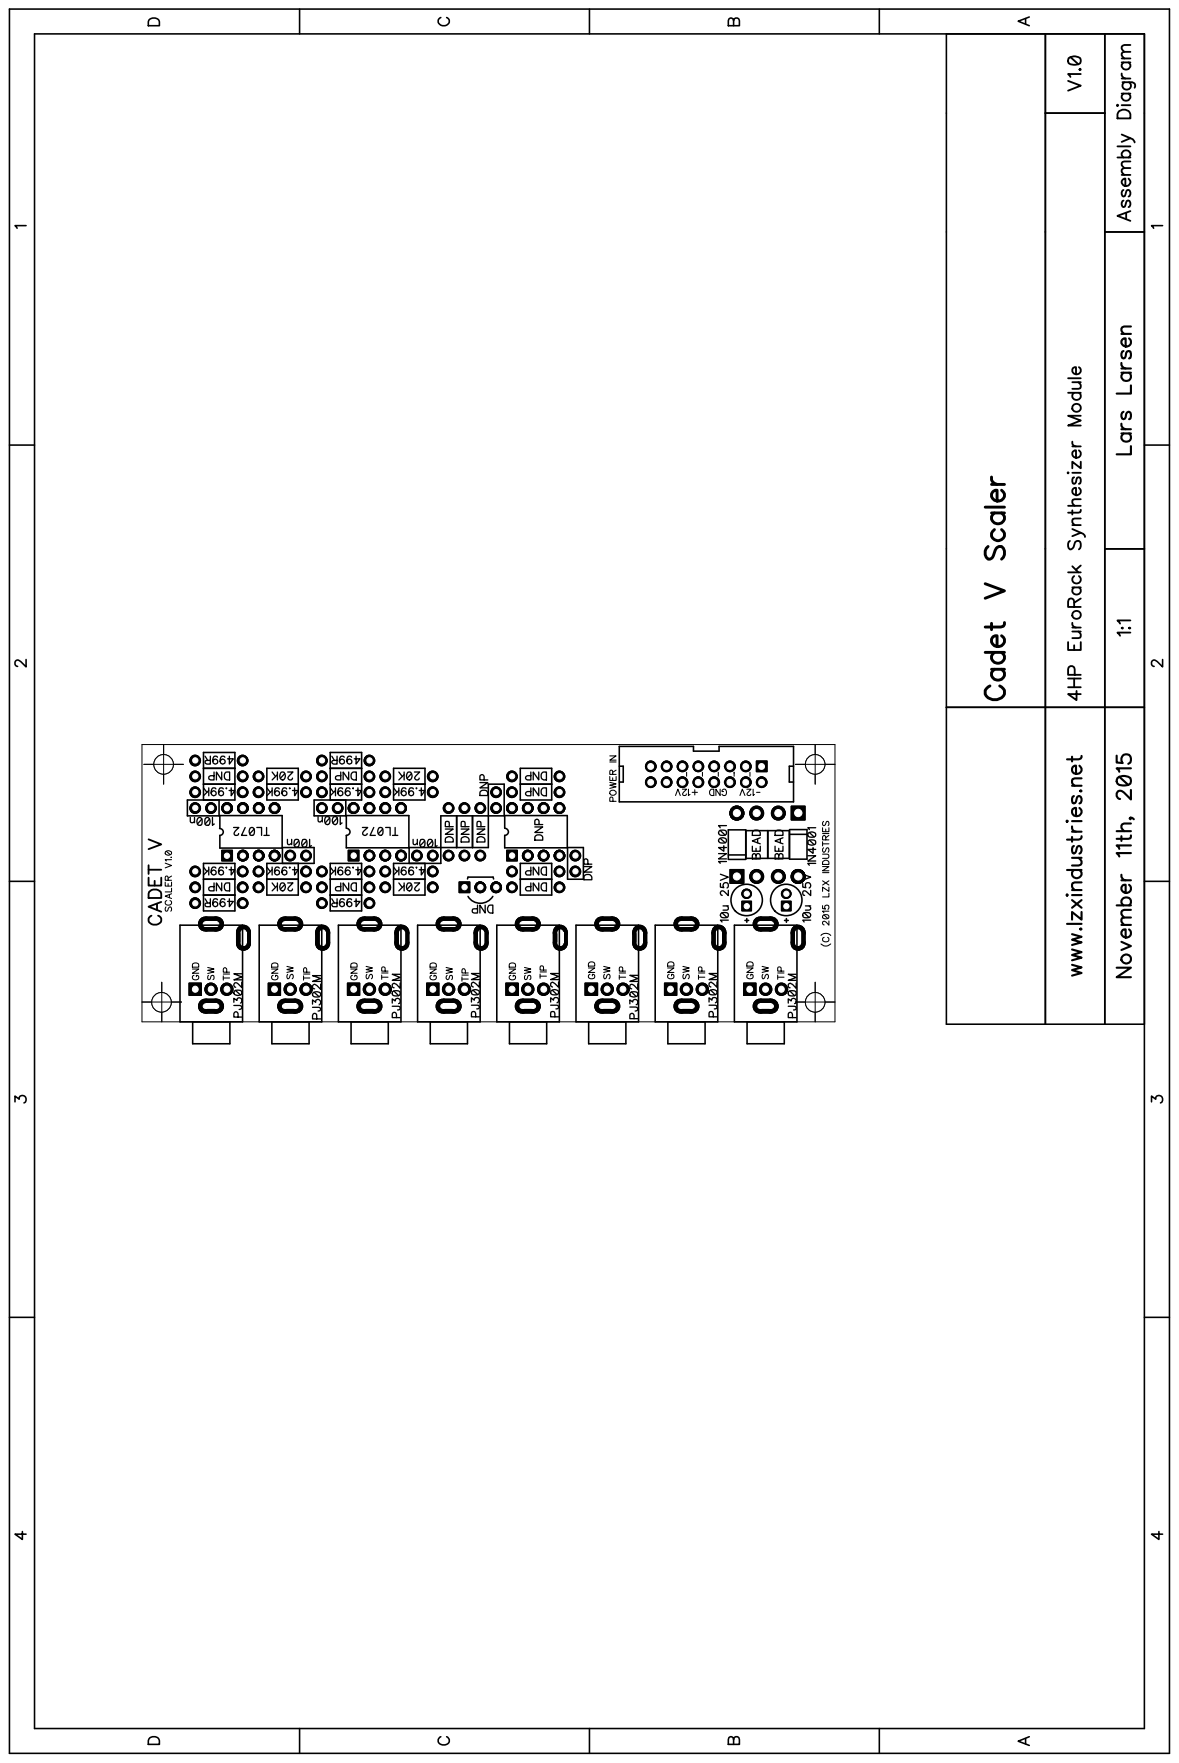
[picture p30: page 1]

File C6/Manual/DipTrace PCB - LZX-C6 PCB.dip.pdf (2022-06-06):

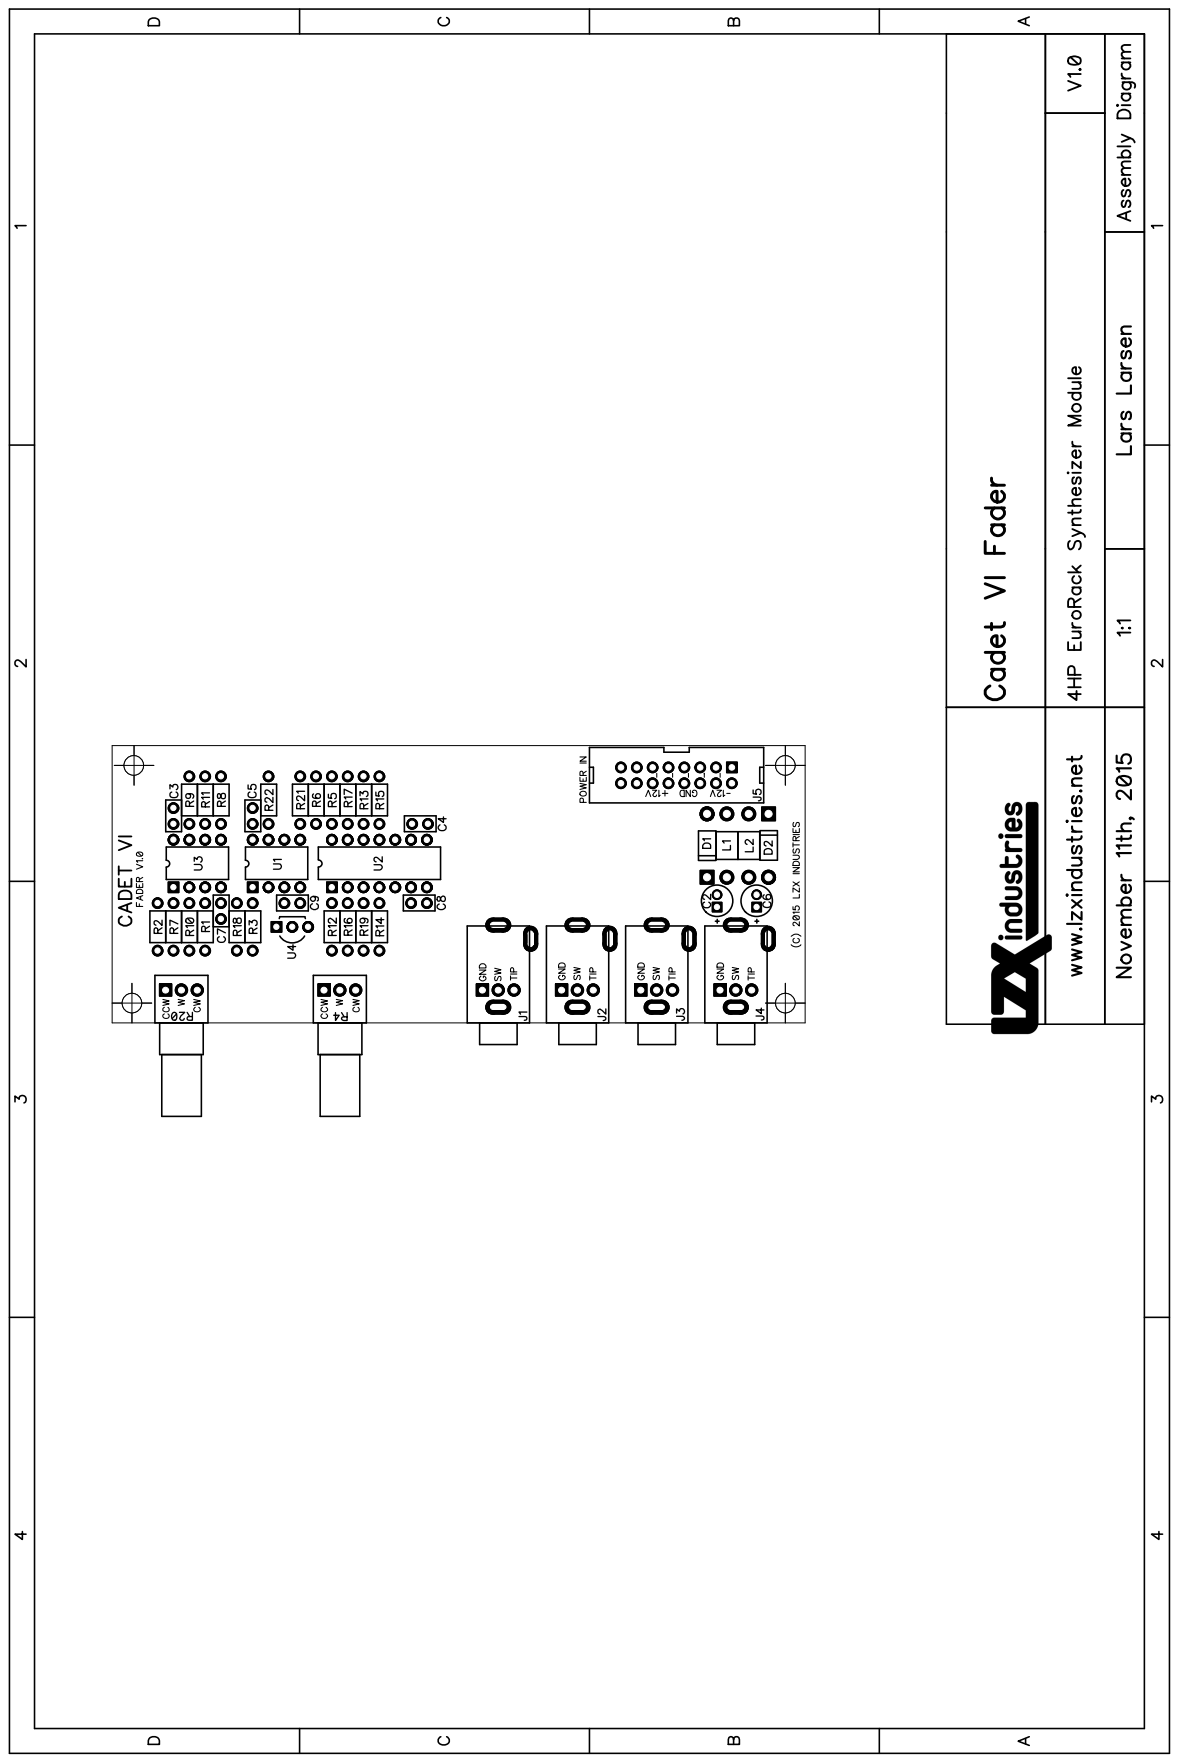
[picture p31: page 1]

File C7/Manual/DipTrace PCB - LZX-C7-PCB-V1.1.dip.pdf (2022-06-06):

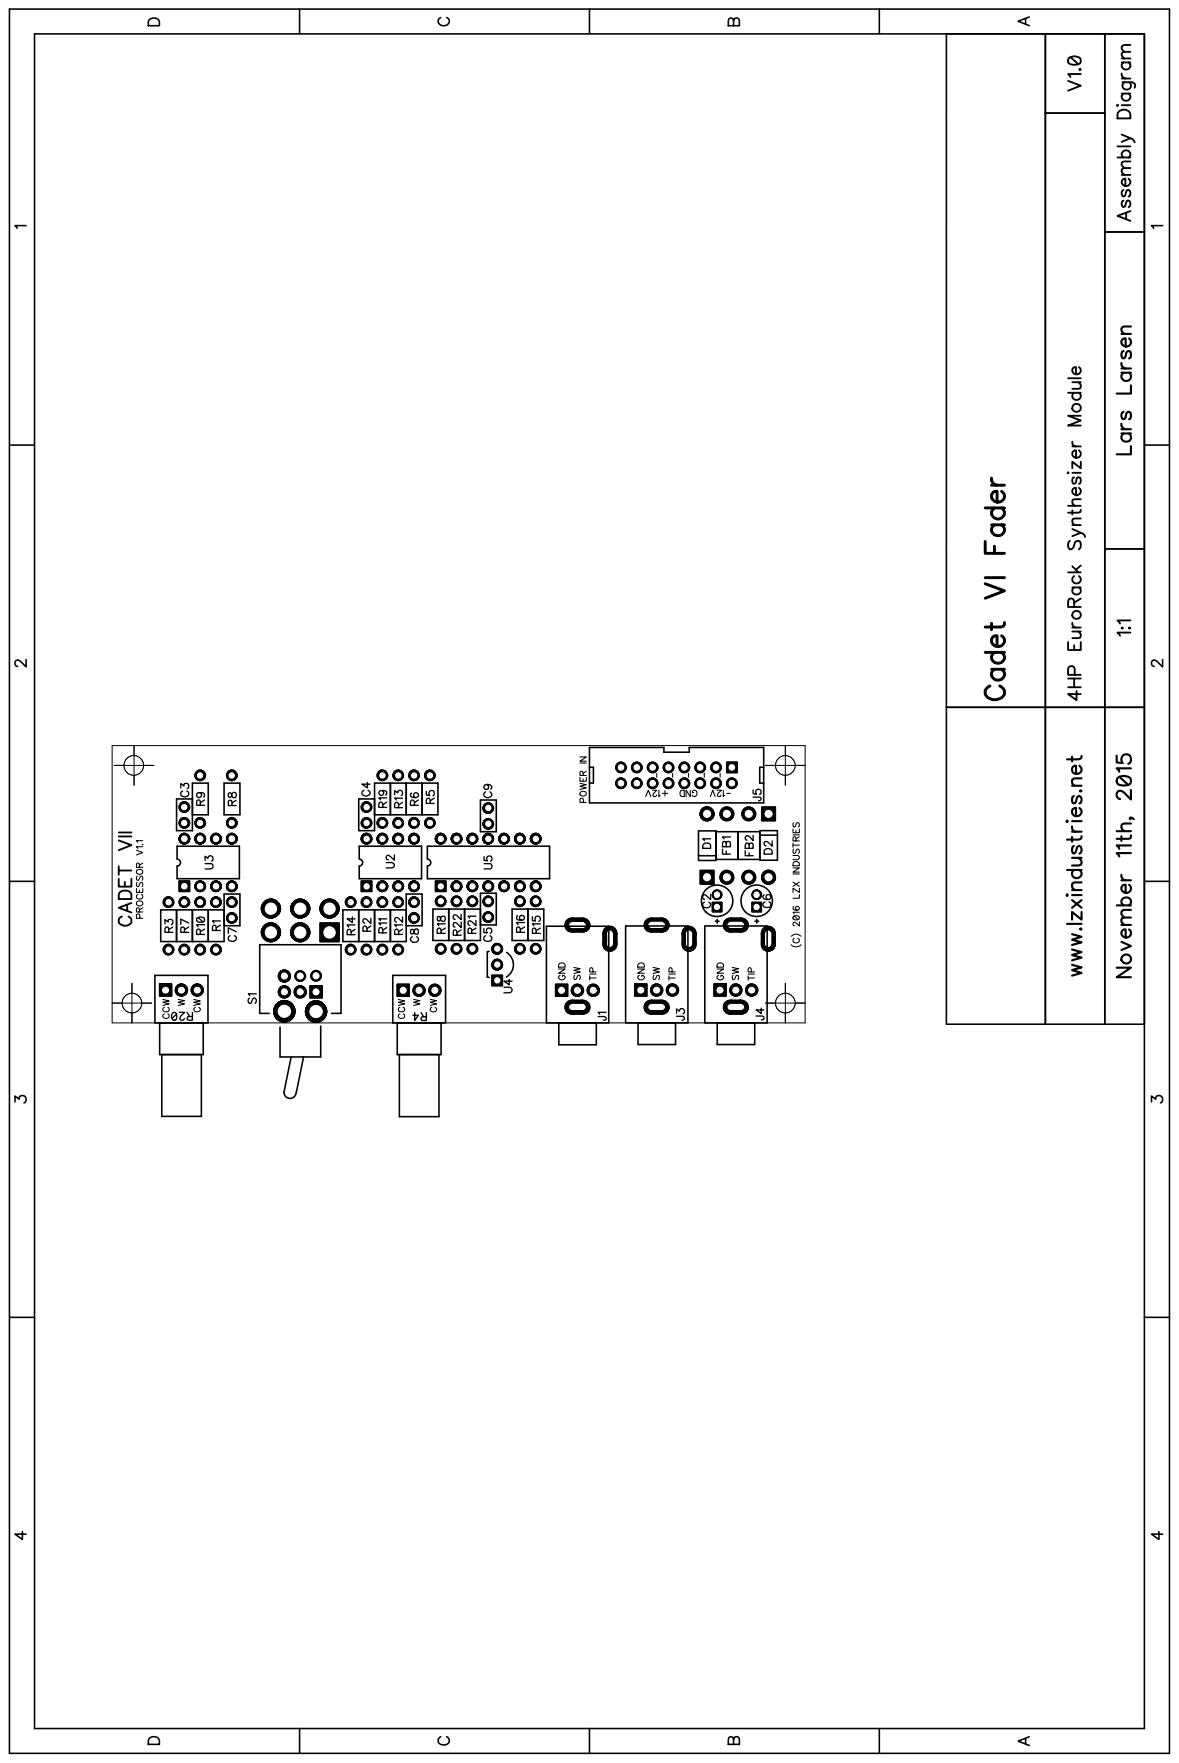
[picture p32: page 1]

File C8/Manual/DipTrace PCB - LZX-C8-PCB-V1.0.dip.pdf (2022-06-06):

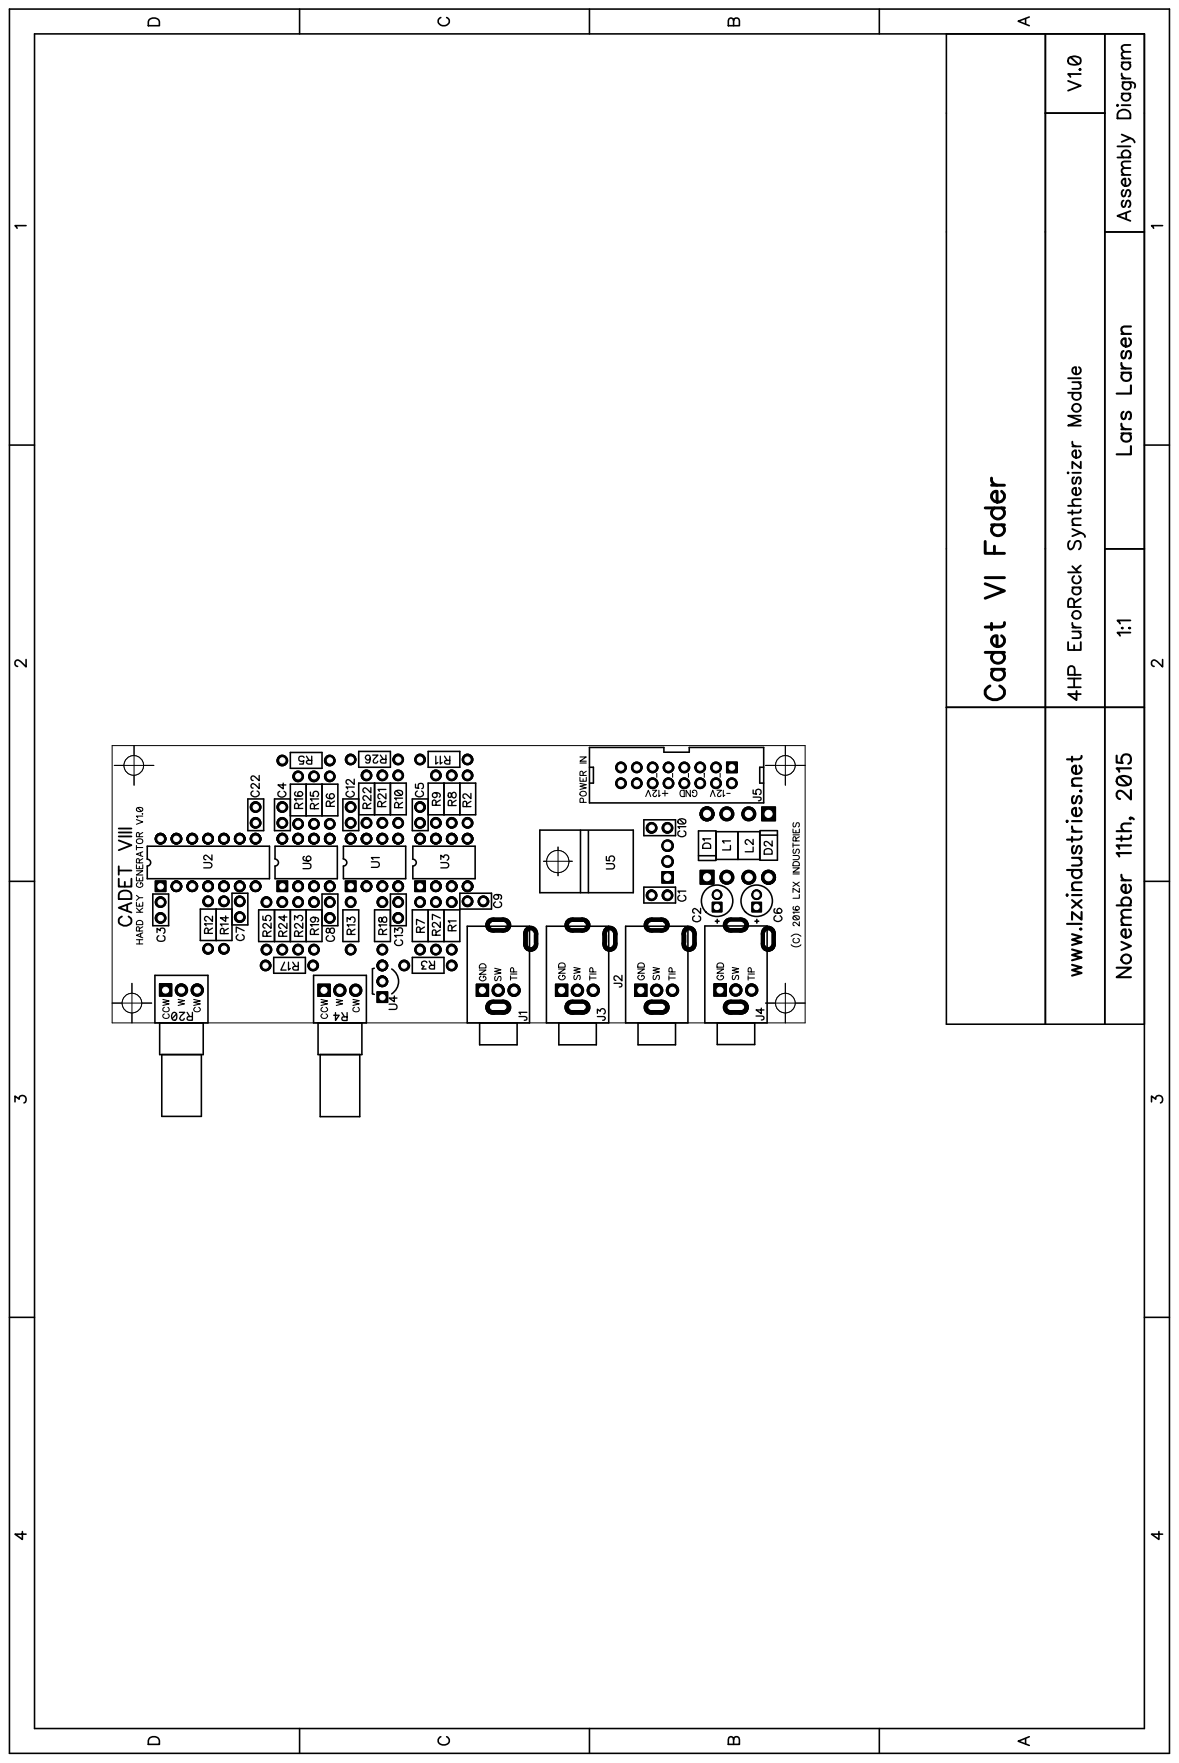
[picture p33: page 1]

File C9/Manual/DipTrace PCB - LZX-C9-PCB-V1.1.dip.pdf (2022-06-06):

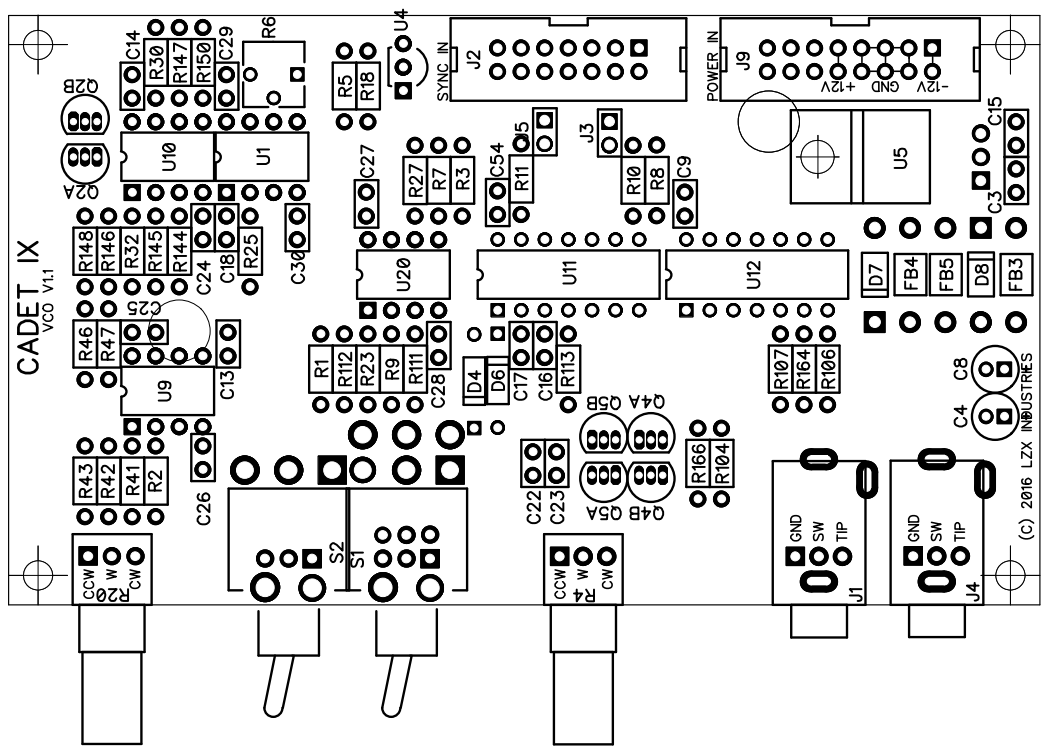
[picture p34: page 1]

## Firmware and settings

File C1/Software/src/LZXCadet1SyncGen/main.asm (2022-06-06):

/***************************************************************************
* Description     : Sync Generator 2.0
* HW-Environment  : AVR MCU ATmega88A
*                   
*                   
* SW-Environment  : Atmega Studio 7.0						
* Author          : Ed Leckie
*				  : Revisions by Lars Larsen
*
* Revision list:
****************************************************************************/
//.include "m168def.inc"
//.include "m328Pdef.inc"
.include "m88Adef.inc"
;*********************************************************
;*	Byte access anywhere in IO or data space
;* 	STORE - Store register in IO or data space
;* 	LOAD  - Load register from IO or data space
;*********************************************************

.MACRO STORE 		;Arguments: Address, Register
	.IF	@0>0x3F
		sts	@0, @1
	.ELSE
		out	@0, @1
	.ENDIF
.ENDMACRO
//
//.MACRO LOAD 		;Arguments: Register, Address
//	#if	@1>0x3F
//		lds	@0, @1
//	#else
//		in	@0, @1
//	#endif
//.ENDMACRO

//#define F_CPU 14318180 //4xNTSC
//#define F_CPU 8000000
//#define F_CPU 16000000
#define F_CPU 13500000

/*Timing*/
//NTSC
#define NTSCLineTime ((F_CPU/15734)-1)
#define NTSCLineTimeH NTSCLineTime>>8
#define NTSCLineTimeL NTSCLineTime&0xFF
#define NTSCHalfLineTime NTSCLineTime/2
#define NTSCHalfLineTimeH NTSCHalfLineTime>>8
#define NTSCHalfLineTimeL NTSCHalfLineTime&0xFF
#define NTSClongsync F_CPU*27/1000000
#define NTSCshortsync F_CPU*2.54/1000000
//#define NTSCshortsync F_CPU*2/1000000
//#define NTSCnormsync F_CPU*4.7/1000000
#define NTSCnormsync F_CPU*5/1000000
#define NTSCF1preeqpulses 6
#define NTSCF1Vertsyncpulses 6
#define NTSCF1posteqpulses 6
//#define NTSCF1preActiveVideolines 16
#define NTSCF1preActiveVideolines 13
//#define NTSCF1ActiveVideolines 237
#define NTSCF1ActiveVideolines 237
#define NTSCF2preeqpulses 7
#define NTSCF2Vertsyncpulses 6
#define NTSCF2posteqpulses 5
//#define NTSCF2preActiveVideolines 16
//#define NTSCF2ActiveVideolines 238
#define NTSCF2preActiveVideolines 14
#define NTSCF2ActiveVideolines 237
#define NTSCBlankTime F_CPU*10/1000000
#define NTSCBlankStart 0x45
#define NTSCLineTimeX8 NTSCLineTime/8
#define NTSCLineTimeX10 4*NTSCLineTime/42

//
// NTSC
//
// Back-porch 1.5us
// Sync 4.7us
// front-porch 4.7us




// Field 1 (63.5us)
// 6 pre-equalizing pulses (0.04H) @ 31.75us
// 6 vert sync pulses (0.07H) @ 31.75us
// 6 post-equalizing pulses (0.04H) @ 31.75us
// 253.5 @ 63.5  
// Field 2 (63.5us)
// 6 pre-equalizing pulses (0.04H) @ 31.75us
// 6 vert sync pulses (0.07H) @ 31.75us
// 5 post-equalizing pulses (0.04H) @ 31.75us
// 254

//PAL
//#define PALLineTime ((F_CPU/15625) - 1)
//#define PALLineTime 511
#define PALLineTime ((F_CPU/15625) - 1)
#define PALLineTimeH PALLineTime>>8
#define PALLineTimeL PALLineTime&0xFF
//#define PALHalfLineTime (((PALLineTime+1)/2)-1)
#define PALHalfLineTime PALLineTime/2
#define PALHalfLineTimeH PALHalfLineTime>>8
#define PALHalfLineTimeL PALHalfLineTime&0xFF
#define PALlongsync F_CPU*27/1000000
#define PALshortsync F_CPU*22/10000000
#define PALnormsync F_CPU*44/10000000
#define PALF1preeqpulses 6
#define PALF1Vertsyncpulses 5
#define PALF1posteqpulses 5
//#define PALF1preActiveVideolines 17
#define PALF1preActiveVideolines 22
//#define PALF1ActiveVideolines 288
#define PALF1ActiveVideolines 280
#define PALF2preeqpulses 5
#define PALF2Vertsyncpulses 5
#define PALF2posteqpulses 4
//#define PALF2preActiveVideolines 17
#define PALF2preActiveVideolines 22
//#define PALF2ActiveVideolines 288
#define PALF2ActiveVideolines 280
#define PALBlankTime F_CPU*12/1000000
#define PALBlankStart 0x45
#define PALLineTimeX8 PALLineTime/8
#define PALLineTimeX10 4*PALLineTime/42

//Atmega8
#define SyncOut             PORTB
#define SyncOutDDR             DDRB
#define SyncC               2    //OCR1B
#define Out_nOdd_Even         0    //
//#define Blank               1    //OCR1A
#define SyncH               1    //OCR1A

//Atmega8
#define SyncInput           PIND
#define SyncInputOut        PORTD
#define SyncInputDDR        DDRD
#define Out_nSyncV			7	 //PD7
#define InSyncV             2    //INT0/PD2
//#define InSyncH             3    //INT1/PD3/OC2B
#define OutBurst            3    //INT1/PD3/OC2B
#define InOdd_Even 			4    //PD4
#define Out_nBlank			5	 //PD5/0C0B
#define EXT_GENLOCK			0	 //PD0
#define EXT_LED				1	 //PD1
#define Out_Odd_nEven		6	 //PD6

#define LinePortIn			PINC
#define LinePortOut			PORTC
#define LinePortDDR			DDRC
#define LineX8				3	//PC3 Blue
#define LineX2				4	//PC4 Green 
#define LineX4				5	//PC5 Red
#define NTSC_PAL_N			0	//PC0

// Burst/Back Porch 4.8us long.

/* Timings */
/* Vertical */
#define F1preeqpulses          r6
#define F1vertsyncpulses       r7
#define F1posteqpulses         r8
#define F1preActiveVideolines  r9
#define F2preeqpulses          r10
#define F2vertsyncpulses       r11
#define F2posteqpulses         r12
#define F2preActiveVideolines  r13
#define F1ActiveVideolines     r24
#define F1ActiveVideolinesL    F1ActiveVideolines
#define F1ActiveVideolinesH    r25

#define F2ActiveVideolines     r16
#define F2ActiveVideolinesL    F2ActiveVideolines
#define F2ActiveVideolinesH    r17
/*Horizontal */
#define BlankTime              r3
#define ShortSyncTime          r14
#define NormSyncTime           r15
#define LongSyncTime           r4
#define LongSyncTimeL          LongSyncTime
#define LongSyncTimeH          r5
#define LineTime               r28
#define LineTimeL              LineTime
#define LineTimeH              r29
#define HalfLineTime     		r30
#define HalfLineTimeL     		HalfLineTime
#define HalfLineTimeH     		r31

/* Counters */
#define syncstate                r19
#define nextframestate           12
#define f1vertsyncstate          11
#define f1posteqpulsestate       10
#define f1preactivevideostate    9
#define f1activevideostate       8
#define f1postactivevideostate   7
#define f2preeqpulsestate        6
#define f2vertsyncstate          5
#define f2posteqpulsestate       4
#define f2preactivevideostate    3
#define f2activevideostate       2
#define f2postactivevideostate   1
#define f1preeqpulsestate        0

/*Misc */

#define acc                    r22
#define accH                   r23
#define NextLineTime           r20
#define NextLineTimeL          NextLineTime
#define NextLineTimeH          r21
#define Counter                r26
#define CounterL               Counter
#define CounterH               r27

#define Genlock                r2

#define VideoMode              r1
#define VideoMode_NTSC_PAL_N   4
//VideoMode bit 2 to 0 colour bar counter during blanking
#define ShortSync              r18
#define NextSyncIsShort		   0x0
#define NextSyncIs2ndShort	   0x1
//#define ShortSyncNotUpdated	   0x2
#define ShortSyncUpdated	   0x2
#define VSyncRisingEdge	   	   0x4

rjmp RESET		; Reset Handler
.org INT0addr
rjmp VSYNC
.org INT1addr
rjmp VSYNC
.org OVF2addr
rjmp TIM2_OVF 	; Timer2 Overflow Handler
.org OC1Aaddr
rjmp TIM1_OCA 	; Timer1 Output compare A Handler
.org OVF1addr
rjmp TIM1_OVF 	; Timer1 Overflow Handler
//.org OC0addr
//rjmp TIM0_OC 	; Timer0 Output compare Handler


TIM2_OVF:
	ldi acc, 0x7
	and acc, VideoMode
	brne TIM2_OVF_RET
	cpi syncstate, f1activevideostate
	breq TIM2_OVF_INC_ADD2
	cpi syncstate, f2activevideostate
	breq TIM2_OVF_INC
	reti
TIM2_OVF_INC_ADD2:
	nop
	nop
TIM2_OVF_INC:
/*
	in acc,LinePortOut
	ldi accH, (1<<LineX8)
	add acc, accH
	andi acc, (1<<LineX8)|(1<<LineX4)|(1<<LineX2)
	out LinePortOut,acc
	reti
*/
	sbis LinePortOut,LineX8
	rjmp TIM2_OVF_INC2
	cbi LinePortOut,LineX8
	nop
	nop
	nop
	nop
	reti
TIM2_OVF_INC2:
	in acc, LinePortOut
	// LineX4 is Red (PC5)
	sbrs acc, LineX4
	rjmp TIM2_OVF_INC3
	ori acc, (1<<LineX8)
	andi acc, ~(1<<LineX4)
	out LinePortOut,acc
	reti
TIM2_OVF_INC3:
	//Line X2 is Green (PC4)
	sbrs acc, LineX2
	rjmp TIM2_OVF_INC4
	ldi acc, (1<<LineX8)|(1<<LineX4) 
	out LinePortOut,acc
	reti
TIM2_OVF_INC4:
	//Line X2 is Green (PC4)
	ldi acc, (1<<LineX8)|(1<<LineX4)|(1<<LineX2)
	out LinePortOut,acc
	reti

TIM2_OVF_RET:
	dec VideoMode
	reti

/*
TIM3_OVF:
  //If genlock == 0 then switch to internal sync
  tst genlock
  brne DEC_GEN
  reti
  //Else decrement genlock
DEC_GEN: 
  mov acc,genlock
  subi acc, 0x1
  mov genlock, acc
  reti
*/

HSYNC:
  //in acc,SyncInput
  //andi acc,(1<<InSyncH)
  //cpi acc, 0x0
  //breq HSYNC_CLR
  //sbi SyncOut, SyncH
  //reti
//HSYNC_CLR:
  //cbi SyncOut, SyncH
  //in LineTimeH,TCNT1H
  //in LineTimeL,TCNT1L
  //out TCNT1H,LineTimeH
  //out TCNT1L,LineTimeL
  ldi accH, 0x0
  ldi acc, 0x0f
  STORE TCNT1H,accH
  STORE TCNT1L,acc
  rjmp TIM1_OVF


VSYNC:
//  in acc,SyncInput
//  andi acc,(1<<InSyncV)
//  cpi acc, 0x0
  sbis SyncInput, InSyncV
  rjmp VSYNC_CLR
  //sbi SyncOut, SyncV
  cbi SyncInputOut, Out_nSyncV
  sbr ShortSync, (1<<VSyncRisingEdge)
  reti
VSYNC_CLR:
  //cbi SyncOut, SyncV
  sbi SyncInputOut, Out_nSyncV
  reti

// ShortSync - Status
// 0x0 - No more Short Syncs
// 0x1 - ShortSync 
// 0x2 - ShortSync 2nd
// 0x4 - ShortSyncUpdated

TIM1_OCA:
  sbrs ShortSync,NextSyncIsShort
  rjmp TIM1A_NORM
  sbrs ShortSync,NextSyncIs2ndShort
  rjmp TIM1A_IGNORESYNC
  //ldi acc,((1<<COM1A1)|(1<<COM1B1)|(1<<COM1B0)|(1<<WGM11)) //mode14, set on compare match clear at TOP
  ldi acc,((1<<COM1A1)|(1<<COM1B1)|(1<<WGM11)) //mode14, clear on compare match set at TOP
  STORE TCCR1A,acc
  cbr ShortSync,(1<<NextSyncIs2ndShort)
  rjmp TIM1A_RET  
TIM1A_IGNORESYNC:
  cbi   SyncOut,SyncH
  //Keep Hsync high for one
  //ldi acc,((1<<COM1B1)|(1<<COM1B0)|(1<<WGM11)) //mode14, set on compare match clear at TOP
  ldi acc,((1<<COM1B1)|(1<<WGM11)) //mode14, clear on compare match set at TOP
  STORE TCCR1A,acc
  sbr ShortSync,(1<<NextSyncIs2ndShort)
  rjmp TIM1A_RET  
TIM1A_NORM:
  //ldi acc,((1<<COM1A1)|(1<<COM1B1)|(1<<COM1B0)|(1<<WGM11)) //mode14, set on compare match clear at TOP
  ldi acc,((1<<COM1A1)|(1<<COM1B1)|(1<<WGM11)) //mode14, clear on compare match set at TOP
  STORE TCCR1A,acc  
TIM1A_RET:  
  cbr  ShortSync,(1<<ShortSyncUpdated)
  reti



//ISR exectued every CSync
TIM1_OVF:
	//cbi  SyncInputOut, EXT_LED
	sbrs VideoMode, VideoMode_NTSC_PAL_N
	rjmp TIM1_PAL_NOPRESCALERCLR
	//NTSC
	ldi	acc, (1<<PSRASY)|(1<<PSRSYNC)
	STORE GTCCR, acc
	ldi acc,((1<<WGM22)) // stop clk 7 Fast PWM
	STORE TCCR2B,acc
	ldi acc,((1<<TOV2)) // stop clk 7 Fast PWM
	STORE TIFR2,acc
	// /NTSC
	// PALBlankStart - 0x40 
	ldi acc, 0x04
	STORE TCNT0, acc
	//Colour bar start
	ldi acc, 0x34
	STORE TCNT2, acc
	ldi acc,((1<<WGM22)|(1<<CS20)) // clk/1 mode 7 Fast PWM
	STORE TCCR2B,acc
//	ldi acc, 0x2
	ldi acc, 0x1
	or  VideoMode, acc
	cbi	LinePortOut, LineX8
	cbi	LinePortOut, LineX4
	cbi	LinePortOut, LineX2
	rjmp TIM1_NEXTLINE

TIM1_PAL_NOPRESCALERCLR:
	// PALBlankStart - 0x40 
	ldi acc, 0x05
	STORE TCNT0, acc
	//Colour bar start
	//Stop Timer2
    //colour bar timer2
	ldi acc,((1<<WGM22)) // stop clk 7 Fast PWM
	STORE TCCR2B,acc
	ldi acc,((1<<TOV2)) // stop clk 7 Fast PWM
	STORE TIFR2,acc
	ldi acc, 0x3C
	STORE TCNT2, acc
    //colour bar timer2
	ldi acc,((1<<WGM22)|(1<<CS20)) // clk/1 mode 7 Fast PWM
	STORE TCCR2B,acc
	//ldi acc, 0x2
	ldi acc, 0x1
	or  VideoMode, acc
	cbi	LinePortOut, LineX8
	cbi	LinePortOut, LineX4
	cbi	LinePortOut, LineX2


TIM1_NEXTLINE:
  //out OCR1BH,NextSyncTimeH
  //out OCR1BL,NextSyncTimeL
  STORE ICR1H,NextLineTimeH
  STORE ICR1L,NextLineTimeL
  //ori  ShortSync,(1<<ShortSyncNotUpdated)
  //Check for Vsync if EXT_GENLOCK enabled
  sbic SyncInput, EXT_GENLOCK
  rjmp TIM1_VSYNCCHECK
  //Clear Ext Sync LED
  cbi  SyncInputOut, EXT_LED
  clr  Genlock
  rjmp TIM1_CNT
//Check for rising edge of Vsync ODD frame
//  sbrs ShortSync, VSyncRisingEdge
TIM1_VSYNCCHECK:
//Alternate Check for rising edge of Vsync ODD frame INTF0 in EIFR
  sbis EIFR, INTF0
  rjmp TIM1_CNT
  sbi  EIFR, INTF0
  //Set Ext Sync LED
  sbi  SyncInputOut, EXT_LED
  clr  Genlock
  //Short Sync
  sbrs ShortSync, NextSyncIsShort
  rjmp TIM1_FIELD
  sbrs ShortSync, NextSyncIs2ndShort
  rjmp TIM1_CNT
TIM1_FIELD:
  cbr ShortSync, (1<<VSyncRisingEdge)
  sbis SyncInput, InOdd_Even
  rjmp TIM1_CNT
//Check for Video Mode
  sbrs VideoMode, VideoMode_NTSC_PAL_N
  rjmp TIM1_PAL
// NTSC
  ldi  CounterH,0x00
  ldi  CounterL,0x03
  ldi  syncstate, f1posteqpulsestate
// /NTSC
  rjmp TIM1_CNT
TIM1_PAL:
//PAL
  ldi  syncstate, f1preactivevideostate
  rjmp F1preactivevideo
// /PAL

TIM1_CNT:  
  sbiw Counter,0x01	
  brne vend
  //Change State
  subi syncstate,0x01
//  breq F1preeq
  cpi  syncstate,f1vertsyncstate
  brne f1poep
  rjmp F1vertsync
  f1poep: 
  cpi  syncstate,f1posteqpulsestate
  brne f1prav
  rjmp F1posteq
  f1prav:
  cpi  syncstate,f1preactivevideostate
  brne f1av
  rjmp F1preactivevideo
  f1av:
  cpi  syncstate,f1activevideostate
  brne f1poav
  rjmp F1activevideo 
  f1poav:
  cpi  syncstate,f1postactivevideostate
  brne f2prep
  rjmp F1postactivevideo 
  f2prep:
  cpi  syncstate,f2preeqpulsestate
  brne f2vs
  rjmp F2preeq 
  f2vs:
  cpi  syncstate,f2vertsyncstate
  brne f2poep
  rjmp F2vertsync
  f2poep:
  cpi  syncstate,f2posteqpulsestate
  brne fprav
  rjmp F2posteq
  fprav:
  cpi  syncstate,f2preactivevideostate
  brne f2av
  rjmp F2preactivevideo
  f2av:
  cpi  syncstate,f2activevideostate
  brne f2poav
  rjmp F2activevideo 
  f2poav:
  cpi  syncstate,f2postactivevideostate
  brne f1prep
  rjmp F2postactivevideo 
  f1prep:
  rjmp F1preeq
  Vend:
  reti



F1vertsync:
  // Clear SyncV 
  //Set vert sync to 30us
  STORE OCR1BH,LongSyncTimeH
  STORE OCR1BL,LongSyncTimeL
  //cbi  SyncOut,SyncV
  sbi  SyncOut,Out_nOdd_Even
  cbi  SyncInputOut,Out_Odd_nEven
  sbi  SyncInputOut,Out_nSyncV
  ldi  CounterH,0x00
  mov  CounterL,F1vertsyncpulses
  inc  Genlock
  ldi  acc, 0xF
  and  Genlock,acc
  //Set LED
  sbi  SyncInputOut, EXT_LED
  sbrc Genlock, 3
  cbi  SyncInputOut, EXT_LED
  //else Clear LED
  rjmp vend

F1posteq:
  // Set SyncV 
  //cbi  SyncOut,SyncV
//  sbi  SyncOut,SyncV
  //Set sync to 2us
  ldi accH,0x0
  STORE OCR1BH,accH
  STORE OCR1BL,ShortSyncTime
  ldi  CounterH,0x00
  mov  CounterL,F1posteqpulses
  rjmp vend

F1preActiveVideo:
  //Set sync to 4us
  ldi accH,0x00
  STORE OCR1BH,accH
  STORE OCR1BL,NormSyncTime
  STORE OCR1AH,accH
  STORE OCR1AL,NormSyncTime  
  // Set SyncV 
  //sbi  SyncOut,SyncV
  cbi  SyncInputOut,Out_nSyncV
  //Set Frequency to be 64us
  movw NextLineTime, LineTime
  //Enable HSYNC
//  clr  ShortSync
  sbr ShortSync,(1<<ShortSyncUpdated)
  cbr ShortSync,(1<<NextSyncIsShort)|(1<<NextSyncIs2ndShort)
  ldi  CounterH,0x00
  mov  CounterL,F1preActiveVideolines
  rjmp vend

F1ActiveVideo:
  //Enable Video
//  ldi accH,0x00
//  STORE OCR1AH,accH
//  STORE OCR1AL,BlankTime  
  STORE OCR0B,BlankTime  
  //Set number of Active Lines
  mov  CounterH,F1ActiveVideolinesH
  mov  CounterL,F1ActiveVideolinesL
  rjmp vend

F1PostActiveVideo:
  //Disable Video
  ldi accH,0xFF
//  STORE OCR1AH,accH
//  STORE OCR1AL,BlankTime  
  STORE OCR0B,accH  
  //Set number of post-Active Lines
  ldi  CounterH,0x00
  ldi  CounterL,0x03
  rjmp vend

F2preeq:
  //Disable blanking timer
  //Setup Short Sync
  //sbi  SyncOut, SyncV
  movw NextLineTime, HalfLineTime
//  ldi  ShortSync, (1<<NextSyncIsShort)
  sbr ShortSync, (1<<ShortSyncUpdated)|(1<<NextSyncIsShort)
  sbr ShortSync, (1<<NextSyncIs2ndShort)
  //Set short sync (2us)
  ldi accH,0x0
  STORE OCR1BH,accH
  STORE OCR1BL,ShortSyncTime
  ldi  CounterH,0x00
  mov  CounterL,F2preeqpulses
  rjmp vend

F2vertsync:
  // Clear SyncV 
  //Set vert sync to 30us
  STORE OCR1BH,LongSyncTimeH
  STORE OCR1BL,LongSyncTimeL
  //cbi  SyncOut,SyncV
  cbi  SyncOut,Out_nOdd_Even
  sbi  SyncInputOut,Out_Odd_nEven
  sbi  SyncInputOut,Out_nSyncV
  ldi  CounterH,0x00
  mov  CounterL,F2vertsyncpulses
  //ldi  syncstate, 0x5
  rjmp vend

F2posteq:
  // Set SyncV 
  //cbi  SyncOut,SyncV
  sbi  SyncInputOut,Out_nSyncV
//  sbi  SyncOut,SyncV
  //Set sync to 2us
  ldi accH,0x0
  STORE OCR1BH,accH
  STORE OCR1BL,ShortSyncTime
  ldi  CounterH,0x00
  mov  CounterL,F2posteqpulses
  rjmp vend

F2preActiveVideo:
  //Set sync to 4us
  ldi accH,0x00
  STORE OCR1BH,accH
  STORE OCR1BL,NormSyncTime
  STORE OCR1AH,accH
  STORE OCR1AL,NormSyncTime  
  // Set SyncV 
  cbi  SyncInputOut,Out_nSyncV
  //Set Frequency to be 64us
  movw NextLineTime, LineTime
  //clr  ShortSync
  sbr ShortSync,(1<<ShortSyncUpdated)
  cbr ShortSync,(1<<NextSyncIsShort)|(1<<NextSyncIs2ndShort)
  ldi  CounterH,0x00
  mov  CounterL,F2preActiveVideolines
  rjmp vend

F2ActiveVideo:
  //Enable Video
//  ldi accH,0x00
//  STORE OCR1AH,accH
//  STORE OCR1AL,BlankTime  
  STORE OCR0B,BlankTime  
  //Set number of Active Lines
  mov  CounterH,F2ActiveVideolinesH
  mov  CounterL,F2ActiveVideolinesL
  rjmp vend

F2PostActiveVideo:
  //Disable Video
  ldi accH,0xFF
//  STORE OCR1AH,accH
//  STORE OCR1AL,BlankTime 
  out OCR0B,accH
  //Set number of post-Active Lines
  ldi  CounterH,0x00
  ldi  CounterL,0x03
  rjmp vend

F1preeq:
  //Disable blanking timer
//  ldi accH,0xFF
//  out OCR1AH,accH
//  out OCR1AL,BlankTime  
//  ldi acc,((1<<COM1B1)|(1<<COM1B0)|(1<<WGM11)) //mode14, set on compare match clear at TOP
//  out TCCR1A,acc
  //Setup Short Sync
  cbi  SyncInputOut, Out_nSyncV
  //Set Frequency to be half (32us)
  movw NextLineTime, HalfLineTime
//  ldi  ShortSync, (1<<NextSyncIsShort)
  sbr ShortSync, (1<<ShortSyncUpdated)|(1<<NextSyncIsShort)
  sbr ShortSync, (1<<NextSyncIs2ndShort)
  //Set short sync (2us)
  ldi accH,0x0
  STORE OCR1BH,accH
  STORE OCR1BL,ShortSyncTime
  ldi  CounterH,0x00
  mov  CounterL,F1preeqpulses
  ldi  syncstate, nextframestate
  rjmp vend


;*************************************




;*************************************
RPALx50Hz: /* For PAL 625 lines @50Hz the synchro signals are negative polarised */
    //PWM for CSYNC and HSYNC
	ldi acc,((1<<WGM13)|(1<<WGM12)|(1<<CS10)) // clk/1
	STORE TCCR1B,acc
	//ldi acc,((1<<COM1A1)|(1<<COM1A0)|(1<<COM1B1)|(1<<COM1B0)|(1<<WGM11)) //mode14, set on compare match clear at TOP
	ldi acc,((1<<COM1A1)|(1<<COM1A0)|(1<<COM1B1)|(1<<WGM11)) //mode14, clear on compare match set at TOP
	STORE TCCR1A,acc
    //PWM for BLANK
	ldi acc,((1<<WGM02)|(1<<CS01)) // clk/8 mode 7 Fast PWM
	STORE TCCR0B,acc
	//ldi acc,((1<<COM0B1)|(1<<COM0B0)|(1<<WGM01)|(1<<WGM00)) //mode7, Fast PWM set on compare match clear at TOP
	ldi acc,((1<<COM0B1)|(1<<WGM01)|(1<<WGM00)) //mode7, Fast PWM clear on compare match set at TOP
	STORE TCCR0A,acc

    //colour bar timer2
	//ldi acc,((1<<WGM22)|(1<<CS21)) // clk/8 mode 7 Fast PWM
	ldi acc,((1<<WGM22)|(1<<CS20)) // clk/1 mode 7 Fast PWM
	STORE TCCR2B,acc
	ldi acc,((1<<WGM21)|(1<<WGM20)) //mode7, Fast PWM OC2A disconnected
	STORE TCCR2A,acc

	//Setup Registers with PAL Settings
	ldi acc,PALF1preeqpulses
	mov F1preeqpulses, acc
	ldi acc,PALF1Vertsyncpulses
	mov F1vertsyncpulses, acc
	ldi acc,PALF1posteqpulses
	mov F1posteqpulses, acc
	ldi acc,PALF1preActiveVideolines
	mov F1preActiveVideolines, acc
	ldi acc,PALF2preeqpulses
	mov F2preeqpulses, acc
	ldi acc,PALF2Vertsyncpulses
	mov F2vertsyncpulses, acc
	ldi acc,PALF2posteqpulses
	mov F2posteqpulses, acc
	ldi acc,PALF2preActiveVideolines
	mov F2preActiveVideolines,acc
	ldi acc,PALnormsync
	mov NormSyncTime, acc
	ldi acc,PALshortsync
	mov ShortSyncTime, acc
	ldi acc,PALlongsync>>8
	mov LongSyncTimeH, acc
	ldi acc,PALlongsync&0xFF
	mov LongSyncTimeL, acc
	ldi F1ActiveVideolinesH,PALF1ActiveVideolines>>8
	ldi F1ActiveVideolinesL,PALF1ActiveVideolines&0xFF
	ldi F2ActiveVideolinesH,PALF2ActiveVideolines>>8
	ldi F2ActiveVideolinesL,PALF2ActiveVideolines&0xFF
	ldi LineTimeH, PALLineTimeH
	ldi LineTimeL, PALLineTimeL
	ldi HalfLineTimeH, PALHalfLineTimeH
	ldi HalfLineTimeL, PALHalfLineTimeL

	ldi acc, (PALLineTime>>3)&0xff
	STORE OCR0A, acc
	ldi acc, (PALBlankTime>>3)&0xff
	mov BlankTime, acc
	STORE OCR0B, acc
	//Colour Bar
	//ldi acc, (PALLineTimeX8>>3)&0xff
	ldi acc, (PALLineTimeX10)&0xff
	STORE OCR2A, acc

	//Set Timer Period (initally to Half line)
	STORE ICR1H,HalfLineTimeH
	STORE ICR1L,HalfLineTimeL
	movw NextLineTime, HalfLineTime
	//Set Sync Time to Long Sync
	STORE OCR1BH,LongSyncTimeH
	STORE OCR1BL,LongSyncTimeL

	//Blank Width (Greater than Timer count to disable)
	ldi accH,0x00 //0xff
	ldi acc,PALBlankTime
	//mov BlankTime,acc
	STORE OCR1AH,accH
	STORE OCR1AL,acc

	//Load F1vertsyncpulses
	ldi  CounterH,0x00
	mov  CounterL,F1vertsyncpulses

	ldi  syncstate, f1vertsyncstate

	ldi acc, 0x0
	STORE TCNT1H, acc
	STORE TCNT1L, acc
	
	ldi acc, PALBlankStart
	STORE TCNT0, acc
	//Colour bar start
	ldi acc, PALBlankStart
	STORE TCNT2, acc

	ret
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

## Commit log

2022-06-06 Initial archive commit
    [LZX-C1-BOM-V1.1.csv, LZX-C1-FPN-V1.0.dxf, LZX-C10-BOM-V1.0.csv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]
2025-01-31 Added modification board for 3.3V 27MHz VCXO alternatives.
    [VIDCLK13M5-REVA-SMT_bom.csv, VIDCLK13M5-REVA-SMT_rfq_jlcpcb_bom.csv, VIDCLK13M5-REVA-SMT_rfq_jlcpcb_xy.csv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]
